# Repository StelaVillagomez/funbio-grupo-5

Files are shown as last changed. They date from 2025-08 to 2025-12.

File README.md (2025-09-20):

# Grupo5-Fun.Bio.
Bienvenidos al GitHub del grupo 5 :) Este repositorio contiene el proyecto realizado por el Grupo 5 de estudiantes del cuarto ciclo de Ingeniería Biomédica para el curso Fundamentos de Biodiseño.
Nuestro objetivo fue resolver un desafío real mediante el diseño y desarrollo de un dispositivo biomédico, aplicando conocimientos en electrónica, modelado 3D, investigación y prototipado.

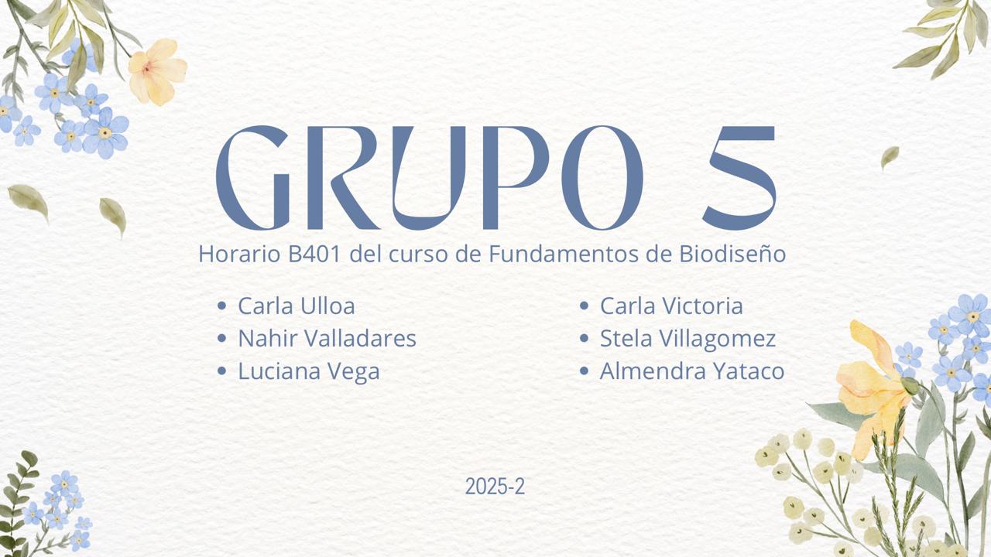
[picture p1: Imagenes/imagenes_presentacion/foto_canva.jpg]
imagen de canva

# Presentación:)

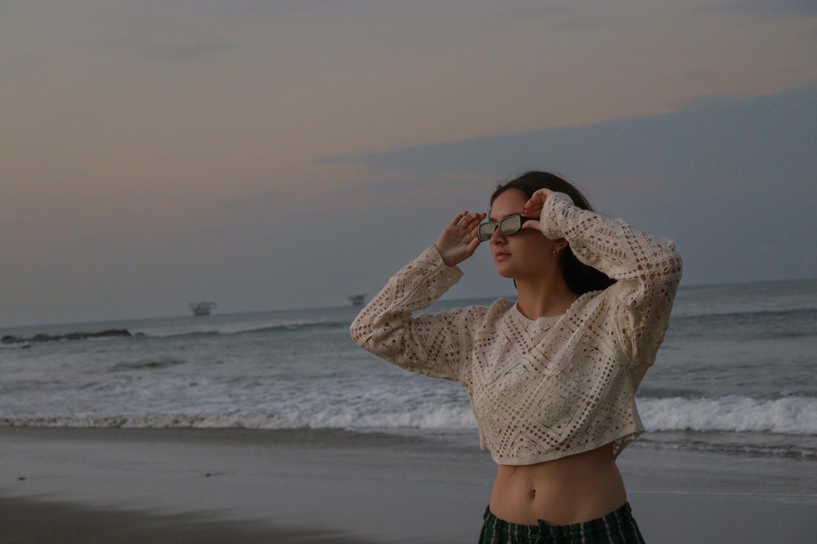
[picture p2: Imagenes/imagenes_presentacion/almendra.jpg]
imagen de WhatsApp

- **Almendra Yataco**
  - **Edad:** 18 años
  - **Sobre mí:** Me gusta compartir con mis amigos y probar cosas nuevas para salir de la rutina 
  - **Rol:** Programadora
  - **Responsabilidades:**
    - Implementar movimientos y funciones
    - Probar y corregir errores del sistema
    - Integrar modelos y elementos gráficos
      
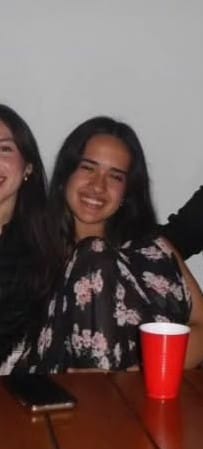
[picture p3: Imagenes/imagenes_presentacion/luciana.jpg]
imagen de WhatsApp

- **Luciana Vega**
  - **Edad:** 18 años
  - **Sobre mí:** Me encanta la tecnología aplicada a la salud. También disfruto salir con mis amigos y aprovechar cada momento al máximo.
  - **Rol:** Modeladora 3D
  - **Responsabilidades:**
    - Crear modelos tridimensionales
    - Aplicar texturas y materiales
    - Optimizar y adaptar los modelos para el proyecto
      
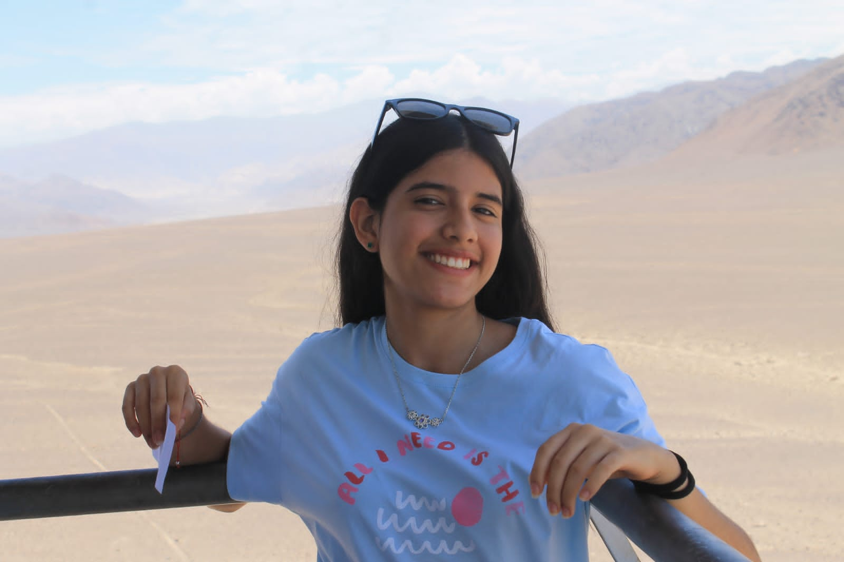
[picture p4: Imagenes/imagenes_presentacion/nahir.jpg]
imagen de WhatsApp

- **Nahir Valladares**
  - **Edad:** 18 años
  - **Sobre mí:** Me encanta la danza, aficionada por la ciencia y la tecnología, siempre dispuesta a aprender
  - **Rol:** Electrónica
  - **Responsabilidades:**
    - Apoyo en el desarrollo del sistema eléctrico
    - Elaboración del sistema y organización de componentes 
    - Verificación de electrónica y funcionamiento del proyecto
      
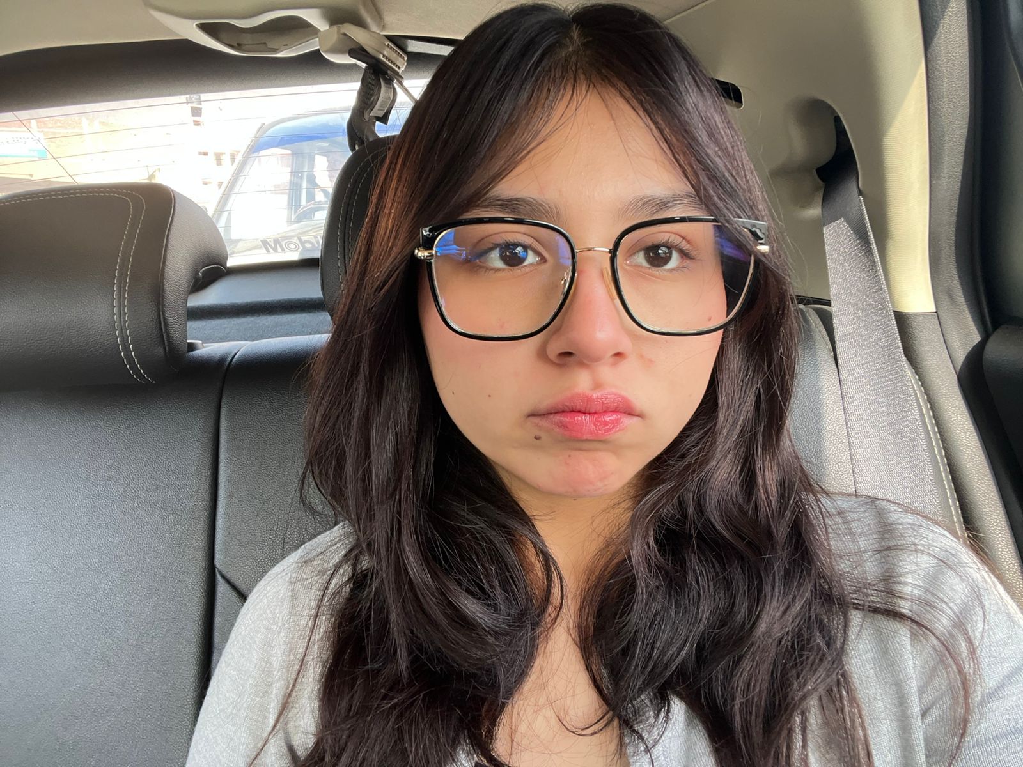
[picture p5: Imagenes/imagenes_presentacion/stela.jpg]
imagen de WhatsApp

- **Stela Villagomez**
  - **Edad:** 18 años
  - **Sobre mí:** Me gusta escuchar música, leer y ver series. Me apasiona resolver problemas, enfrentar nuevos retos y aprender cosas nuevas.
  - **Rol:** Coordinadora General
  - **Responsabilidades:**
    - Organización y coordinación del equipo
    - Planificación y supervisión de actividades
    - Asegurar el cumplimiento de los objetivos del grupo
      
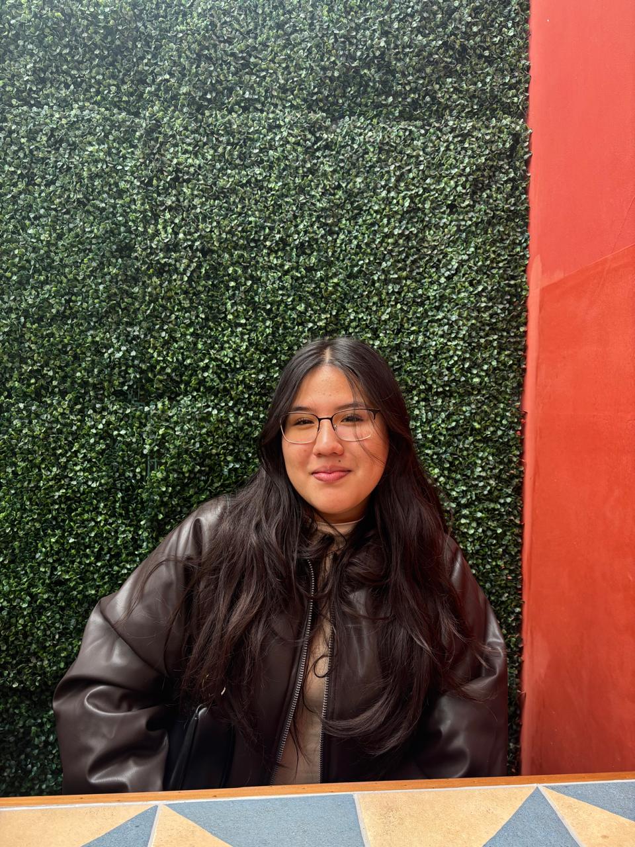
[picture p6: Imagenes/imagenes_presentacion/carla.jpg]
imagen de WhatsApp

- **Carla Victoria**
  - **Edad:** 18 años
  - **Sobre mí:** Ingeniera biomédica enfocada en crear soluciones que unan la ciencia y la tecnología al servicio de la salud.
  - **Rol:** Investigadora
  - **Responsabilidades:**
    - Buscar información relevante para el proyecto
    - Analizar y seleccionar datos útiles
    - Compartir hallazgos con el equipo
      
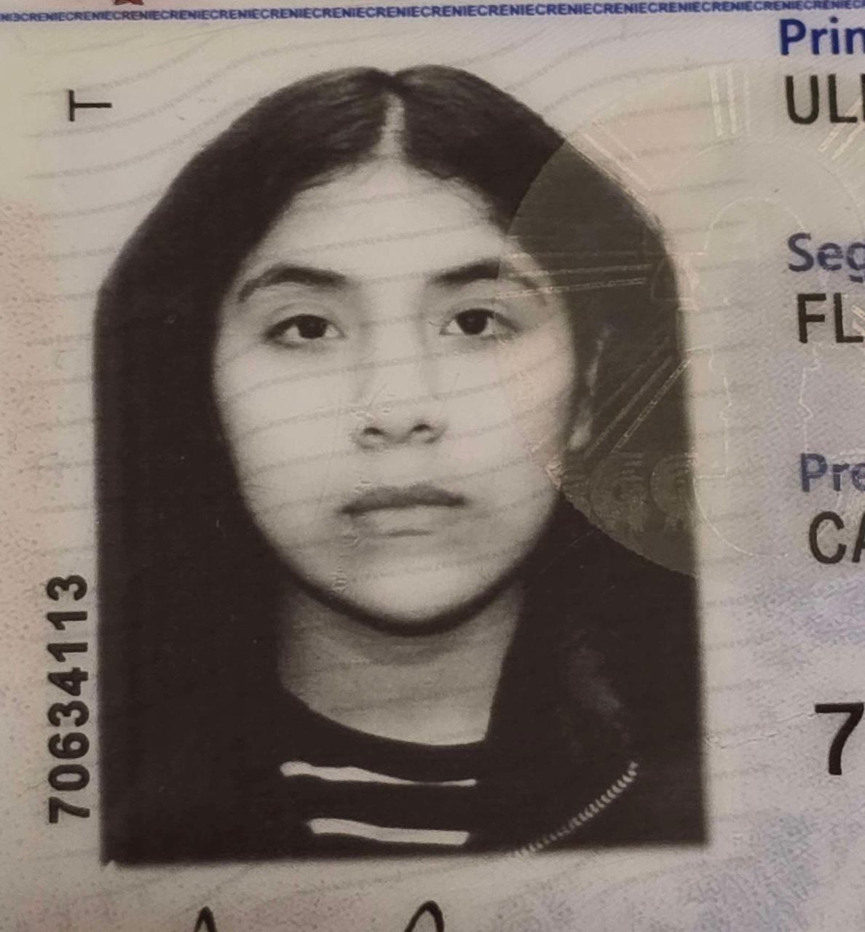
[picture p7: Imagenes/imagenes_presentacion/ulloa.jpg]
imagen de WhatsApp

- **Carla Ulloa**
  - **Edad:** 18 años
  - **Sobre mí:** Apasionada por las imágenes biomédicas y el desarrollo de nuevas tecnologías
  - **Rol:** Diseño 3D y Gestora del Repositorio
  - **Responsabilidades:**
    - Diseño y modelado 3D de estructuras y dispositivos biomédicos utilizando software especializado
    - Optimización y adaptación de modelos 3D para su aplicación en tecnologías biomédicas
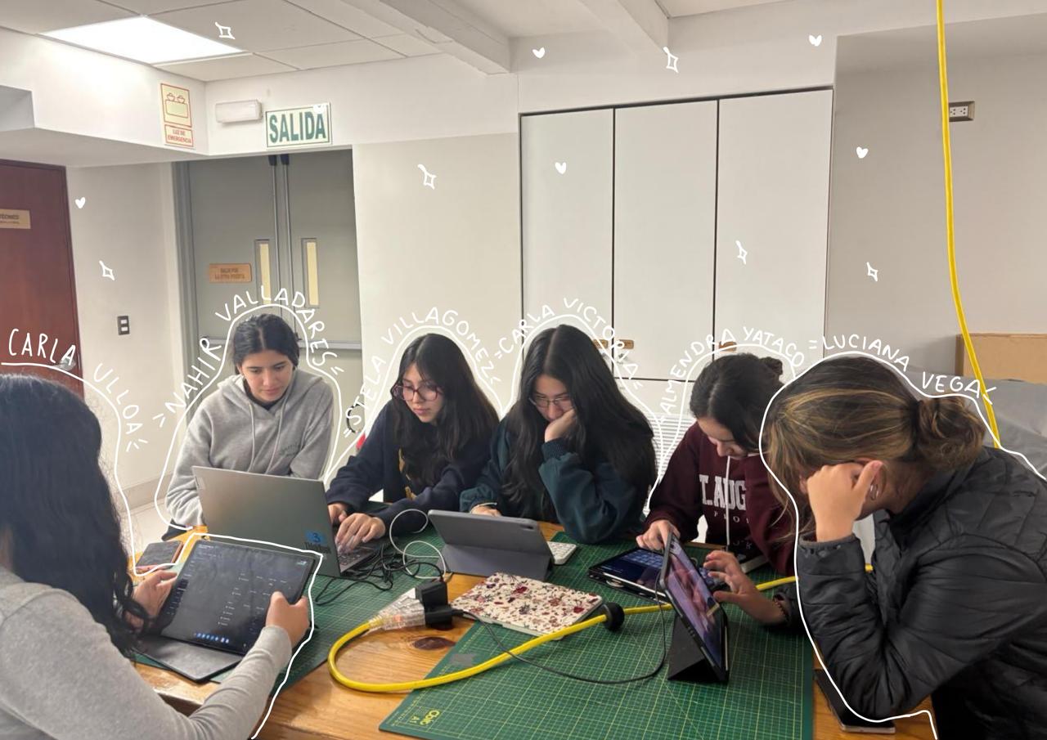
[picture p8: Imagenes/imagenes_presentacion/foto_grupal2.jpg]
imagen de WhatsApp


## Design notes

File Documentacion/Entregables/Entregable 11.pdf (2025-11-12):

# ENTREGABLE 11

### Integrantes: Carla Ulloa Florián Nahir Valladares Santur Luciana Vega Llanos Carla Victoria Quispe Stela Villagomez Altamirano Almendra Yataco Diaz

### Profesor: Juan Manuel Zuñiga

### Curso: Fundamentos de Biodiseño

2025

### 1. VERIFICACIÓN DEL DISEÑO SOFTWARE

Lista de funcionalidades

Función | Mecanismo
Recolección de fecha de la sesión de rehabilitación | Recepción de datos ingresados por el usuario sobre el día, mes y año de la sesión.
Recolección de datos de flexión de la mano (máximo anatómico) | Recepción de datos mediante sensor flex y el ESP32
Muestra del progreso sesión a sesión mediante una gráfica (Flexión vs tiempo) | Procesamiento de datos mediante aplicaciones de google (google sites, google sheets, etc)
Ordena la repetición del movimiento. | Al presionar un botón en la pantalla el usuario ordenará al exoesqueleto que repita la función de extender

Diseño de la interfaz:

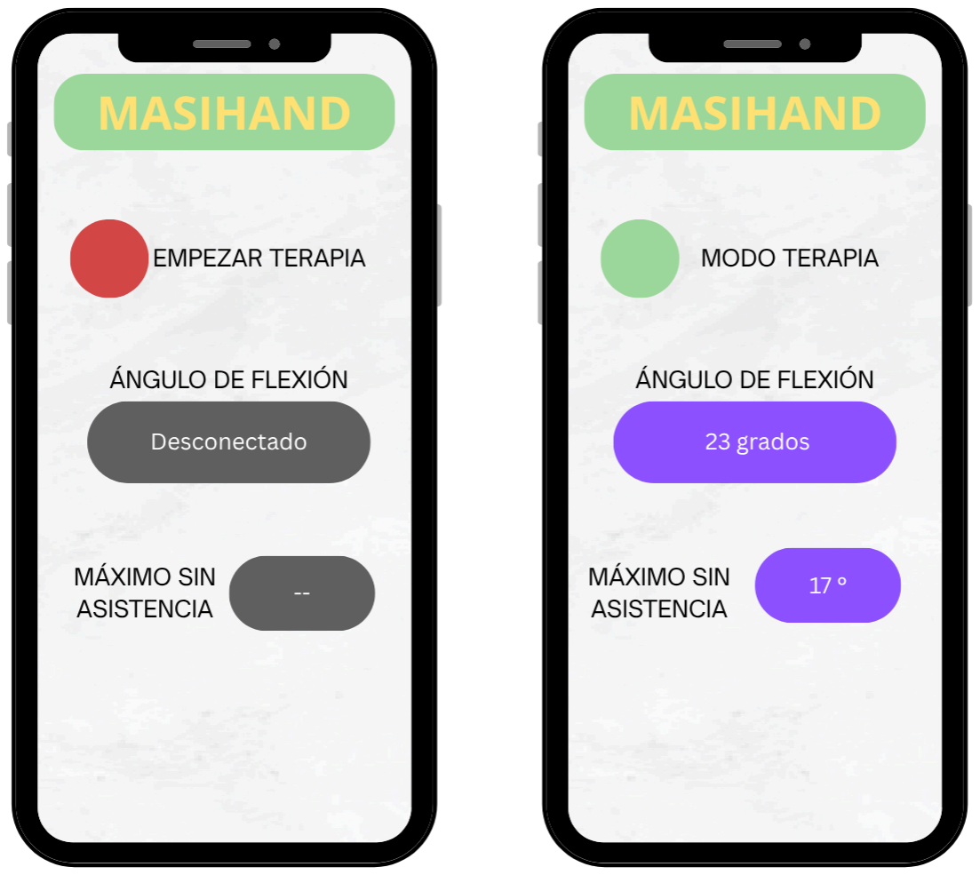
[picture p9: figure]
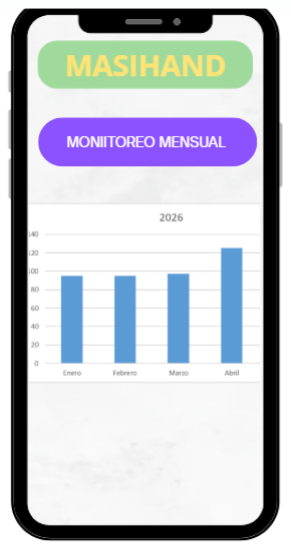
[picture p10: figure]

### 2. VERIFICACIÓN DEL DISEÑO HARDWARE

Preguntas de verificación

- ¿Cuánto peso debe tener el dispositivo?

El guante debe ser liviano para no causar fatiga. El conjunto total (guante, muñequera y caja externa) no debe superar los 700 gramos. Se verificará pesando cada parte y realizando una prueba de confort con el usuario. El diseño cumple si el peso total no excede los 700 g y no genera molestias tras una sesión de 30 minutos.

- ¿Cuánto tiempo debe durar la batería del dispositivo?

El guante, alimentado por baterías de 7 voltios, debe funcionar al menos durante tres sesiones de 30 minutos sin recarga, garantizando continuidad en la terapia. Se verificará mediante una prueba de descarga con el sistema activo, y se aceptará si mantiene su rendimiento por un mínimo de 90 minutos continuos.

- ¿Qué fuerza debe ejercer el guante para abrir los dedos del paciente?

El sistema debe generar entre 10 y 20 newtons por dedo para asistir la extensión y vencer la espasticidad moderada. La fuerza se medirá con un dinamómetro o sensor de carga. El dispositivo será aceptado si alcanza al menos 10 N por dedo con movimientos suaves y controlados.

- ¿Cómo debe funcionar el botón físico de control?

El guante posee un botón externo que inicia o detiene el movimiento. Debe ser accesible, resistente y responder con rapidez. Se probará su durabilidad con pruebas de pulsaciones y su tiempo de respuesta. Cumple el requisito si detiene el motor en menos de 0.5 segundos y mantiene un funcionamiento estable.

- ¿Qué precisión deben tener los sensores de flexión del guante?

Los sensores que miden el ángulo de movimiento deben tener una precisión de ±5° respecto a un goniómetro clínico. Se verificará comparando ambas lecturas, y el sistema será aceptado si el error no supera los ±5°.

- ¿Cómo se garantiza la seguridad del usuario durante la terapia?

El guante no debe generar calor excesivo ni movimientos bruscos. Su temperatura superficial debe mantenerse por debajo de 45 °C y los materiales deben ser cómodos y no irritantes. Se verificará mediante pruebas térmicas y de uso, y se aprobará si no causa molestias ni lesiones.

Requerimiento de Diseño | Resultado del Test
Se deben incorporar flexómetros que registren los ángulos máximos de flexión de los dedos. | Se integraron cinco flexómetros, uno por dedo, capaces de medir el ángulo de flexión y registrar el valor máximo alcanzado durante la terapia.
El sistema debe realizar el movimiento de | El movimiento de extensión se logra

extensión de los dedos mediante un mecanismo controlado. | mediante la tracción de hilos accionados por motores DC gearbox, que tiran de cada dedo de manera sincronizada para asistir la extensión.
Se debe seleccionar un sistema de ajuste que permita fijar el dispositivo en la mano del usuario durante su uso. | En este diseño se utilizó velcro para sujetar el exoesqueleto a cada dedo, permitiendo un ajuste firme, anatómico y fácil de colocar o retirar.
El sistema debe poder ser operado fácilmente por el terapeuta o el paciente. | El dispositivo fue diseñado con una interfaz clara y controles accesibles, lo que permite que tanto el terapeuta como el usuario pueda manipularlo sin dificultad durante la terapia.
El sistema debe visualizar el progreso del paciente a lo largo de las sesiones terapéuticas. | Se incorporó una función de visualización gráfica que muestra la evolución de la flexión de los dedos en función del tiempo mediante aplicaciones de google, permitiendo comparar los resultados sesión a sesión.

### 3. VERIFICACIÓN DEL DISEÑO

Tabla de verificación del prototipo
Funcionalidad | Cumplimiento
Sí | No
Realiza el movimiento de extensión de los dedos mediante tracción de hilos controlada por motores | X
Se calibra previamente el ángulo máximo alcanzable por cada dedo antes de iniciar la terapia | | X
Detecta el intento de extensión voluntaria del paciente y activa la asistencia automáticamente | | X
Limita la fuerza aplicada por los motores para evitar sobreextensión o daño en las articulaciones | X
Mide los ángulos de articulación en tiempo real durante la sesión | | X
El sistema se enciende y | X

apaga mediante un botón

El guante se adapta anatómicamente a la mano del paciente sin generar puntos de presión | X
El sistema puede ser operado fácilmente por el terapeuta o el paciente | X
Permite obtener, procesar, transmitir y almacenar los datos de cada sesión | | X

Tabla de requerimientos

Video del funcionamiento del circuito con el código implementado:

WhatsApp Video 2025-11-08 at 17.14.00.mp4 (https://drive.google.com/file/d/1Z69DmLE_9ussa5wDSN-QYyFBH8f0N9FN/view?usp=drive_link)

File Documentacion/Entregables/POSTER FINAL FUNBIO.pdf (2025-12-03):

Introducción

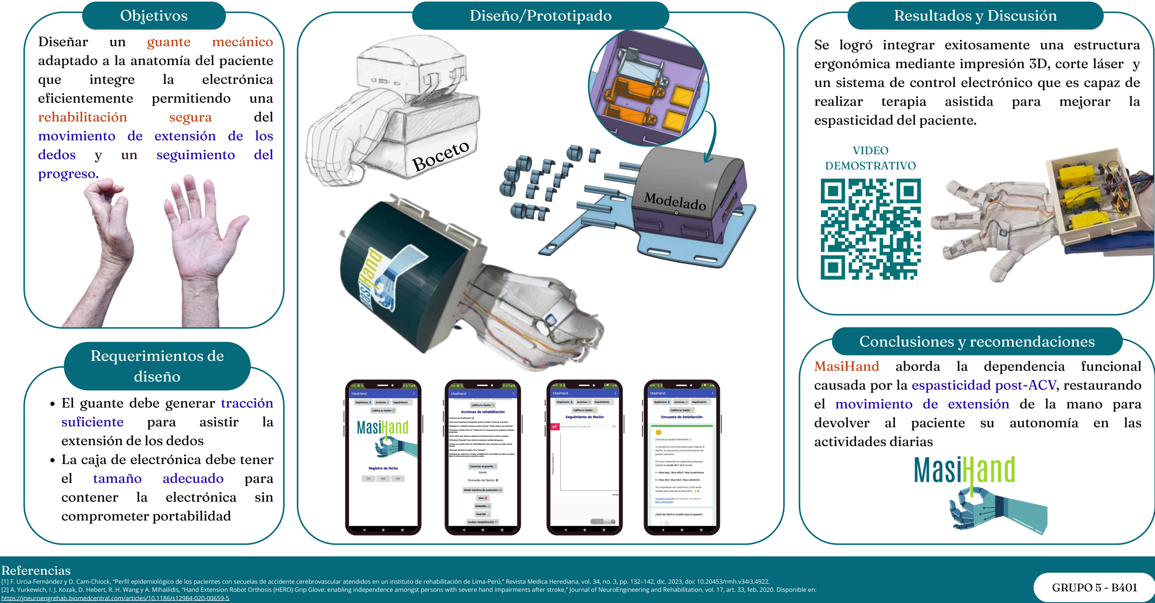
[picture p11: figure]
Objetivos; Modelado; Diseño/Prototipado; Resultados y Discusión; Conclusiones y recomendaciones; Requerimientos de diseño; El guante debe generar tracción; suficiente; para; asistir; extensión de los dedos La caja de electrónica debe tener; tamaño; adecuado; contener la electrónica sin comprometer portabilidad; Boceto; VIDEO DEMOSTRATIVO; MasiHand aborda la dependencia funcional; actividades diarias; GRUPO 5 - B401; Diseñar; guante; mecánico; adaptado a la anatomía del paciente; que; integre; electrónica; eficientemente permitiendo una; rehabilitación; segura; del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

causada por la espasticidad post-ACV, restaurando el movimiento de extensión de la mano para devolver al paciente su autonomía en las

Car

M

la Ulloa, Nahir

A

Valladares,

S

Luciana Ve

I

ga, C

H

arla Victori

A

a, Stela Villa

N

gomez y Alm

D

endra Yataco
Fundamentos de Biodiseño 2025-2, Ingeniería Biomedica, Facultad de Ciencias e Ingenieria

El ACV hemorrágico representa una causa mayor de discapacidad motora. Una de sus secuelas es la hemiplejía del cuerpo que afecta severamente la extremidad superior generando espasticidad y una flexión permanente de la mano, lo que compromete la independencia del paciente al realizar sus actividades de la vida diaria (AVD).

Se logró integrar exitosamente una estructura ergonómica mediante impresión 3D, corte láser y un sistema de control electrónico que es capaz de realizar terapia asistida para mejorar la

[1] F. Urcia-Fernández y D. Cam-Chiock, “Perfil epidemiológico de los pacientes con secuelas de accidente cerebrovascular atendidos en un instituto de rehabilitación de Lima-Perú,” Revista Medica Herediana, vol. 34, no. 3, pp. 132–142, dic. 2023, doi: 10.20453/rmh.v34i3.4922.
[2] A. Yurkewich, I. J. Kozak, D. Hebert, R. H. Wang y A. Mihailidis, “Hand Extension Robot Orthosis (HERO) Grip Glove: enabling independence amongst persons with severe hand impairments after stroke,” Journal of NeuroEngineering and Rehabilitation, vol. 17, art. 33, feb. 2020. Disponible en:
[3] E. Koltzi, D. Tzovaras, I. Kostavelis, P. Sideridis y K. Piliounis, “System and method for stroke rehabilitation using position feedback based exoskeleton control,” U.S. Patent 11,141,341 B2, 12-oct-2021.
[4] R. J. Adams, C. M. Westbrook y C. W. Olinger, “System, device and method for tracking the human hand,” U.S. Patent 11,696,704 B1, 11-jul-2023.

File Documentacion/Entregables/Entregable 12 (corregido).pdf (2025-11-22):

# ENTREGABLE 12

Integrantes:
Carla Ulloa Florián
Nahir Valladares Santur
Luciana Vega Llanos
Carla Victoria Quispe
Stela Villagomez Altamirano Almendra Yataco Diaz

Profesor:
Juan Manuel Zuñiga

Curso:
Fundamentos de Biodiseño

2025

PLAN DE USABILIDAD BASADO EN EVIDENCIAS Sección del
plan
¿Qué es? | ¿Qué hacer? | ¿Qué evidencia deben
incluir?

Contexto de
uso

El guante mecánico con
exoesqueleto
(“MasiHand”) | fue
desarrollado | con el
propósito de asistir en el
tratamiento | de | una
mano | en | tensión
permanente | en | una
paciente de 55 años. El
dispositivo | será
utilizado dentro de un
centro de rehabilitación,
bajo la supervisión del
doctor | o | terapeuta
responsable del caso,
quien se encargará de
garantizar | su | uso
adecuado | y | de
monitorear la evolución
del paciente en cada
sesión.
Para iniciar la sesión, el personal especializado
ayuda a colocar el
guante favoreciendo la
flexión de la muñeca, lo
cual genera la apertura
de los dedos y permite
posicionar el dispositivo
correctamente sobre la
mano. | Una | vez
colocado, se ajustan los
velcros individuales de
cada | dedo | para
asegurarlo al guante.
Posteriormente, se
posiciona la férula y se
fija mediante el velcro
correspondiente, junto

El público objetivo de
MasiHand son pacientes
que presentan una mano
en flexión en distintos
grados de severidad y
que buscan recuperar el
movimiento | de
extensión de su mano
afectada para retomar
actividades diarias y
favorecer | su
independencia
funcional. Debido a
estas necesidades, el
dispositivo | será
utilizado en un centro
de rehabilitación bajo la
supervisión del doctor o
terapeuta encargado del
caso.
En este entorno, el
profesional de salud
asistirá al paciente en la colocación correcta del
guante en cada sesión.
Durante | la | sesión
introductoria, | el
terapeuta explicará el
funcionamiento general
del | dispositivo | y
realizará la calibración
de los ángulos máximos
de las articulaciones de
los dedos del paciente,
con el fin de establecer
un | rango | de
movimiento seguro y
evitar | dolor | y/o
hiperflexión

Se adjunta el modelado
final

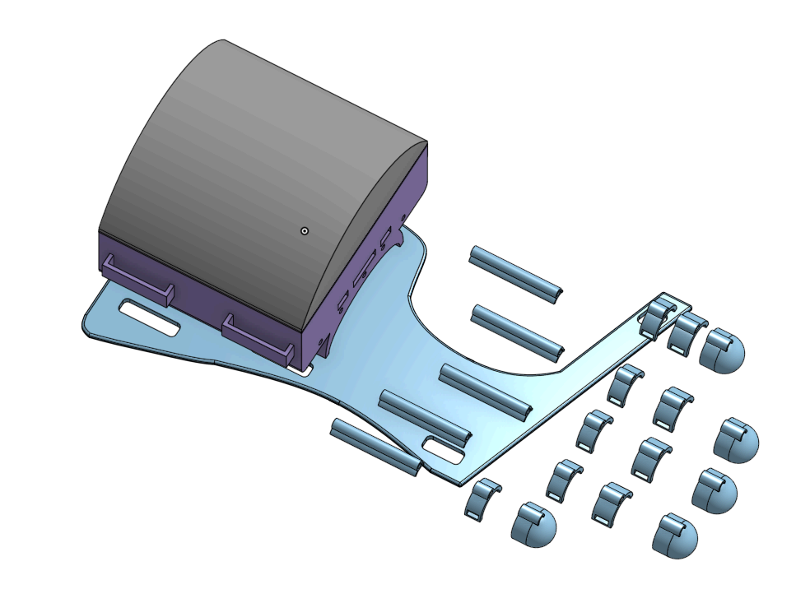
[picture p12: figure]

En la siguiente foto se
muestran los soportes
para los componentes
dentro de la caja de la
muñequera. | Las | 2
cajitas | cuadradas
corresponden | a | los
soportes para drivers.
Mientras que las otras 3
piezas son soportes para
los motores gearbox
yellow

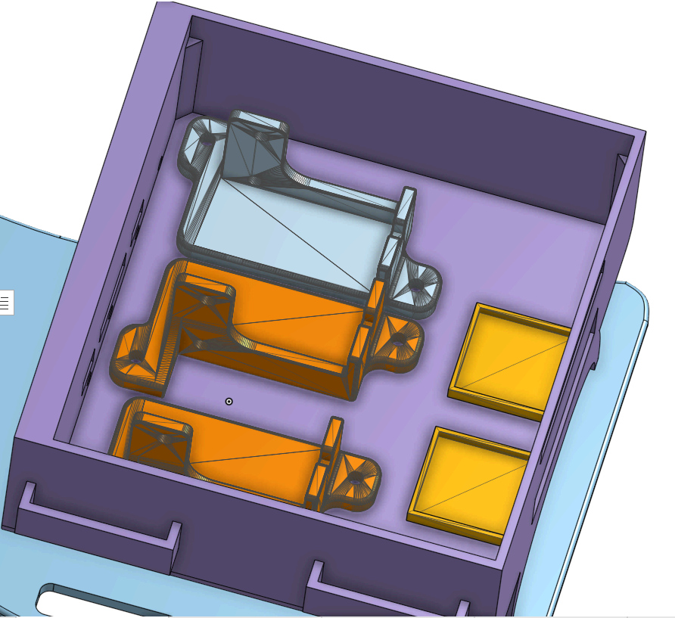
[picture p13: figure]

al | soporte | de | la
muñequera.
Con | todos | | los
componentes ajustados,
la | paciente | queda
preparada | para
comenzar su sesión de
rehabilitación. En la
sesión introductoria, los
ángulos máximos de
flexión son establecidos
y guardados. Como
primer paso, el paciente
intentará | abrir | lo
máximo que pueda con
su propia fuerza, luego
el dispositivo registra
este dato y lo guarda en
una | gráfica | | para
observar su progreso.
Luego, el dispositivo
activa su asistencia
activa para culminar el
movimiento de flexión.

Una vez definida esta
calibración inicial, el
proceso | de
rehabilitación incluirá
cuatro sesiones activas
de flexión de entre 2 y 3
minutos | cada | una,
intercaladas | con
descansos de 2 minutos,
según el criterio del
profesional a cargo.
Este | conjunto | de
sesiones se realizará
tres veces por semana,
en | días | alternados,
siguiendo un esquema
de | uso | regular | y
progresivo que busca
favorecer | la
recuperación | del
movimiento funcional.

Finalmente se adjunta
una foto del prototipo
para la extensión de un
dedo

Perfil del
usuario
El | usuario | posee
habilidades cognitivas
tales | | como
conocimiento | en
costura, un estado de
conciencia lúcido,en el
caso | de | sus
características | físicas
posee | hemiplejia
derecha espástica post
ACV hemorrágico , no
obstante muestra alta
motivación | por
recuperar autonomía en
actividades.
El | pronóstico
neurológico establece
un | déficit | motor
residual permanente y
El | usuario | | posee
limitaciones debido a su
leve | disartria,
ocasionándole | una
espasticidad moderada
con una pobre apertura
voluntaria en la mano
derecha ,pues esta mano
se encuentra en un
estado | de | flexión
permanente, adicional
presenta una limitación
cognitiva | tal | como
déficit motor residual
permanente.
En | cuanto | a | la
movilidad, la paciente
realiza la marcha de

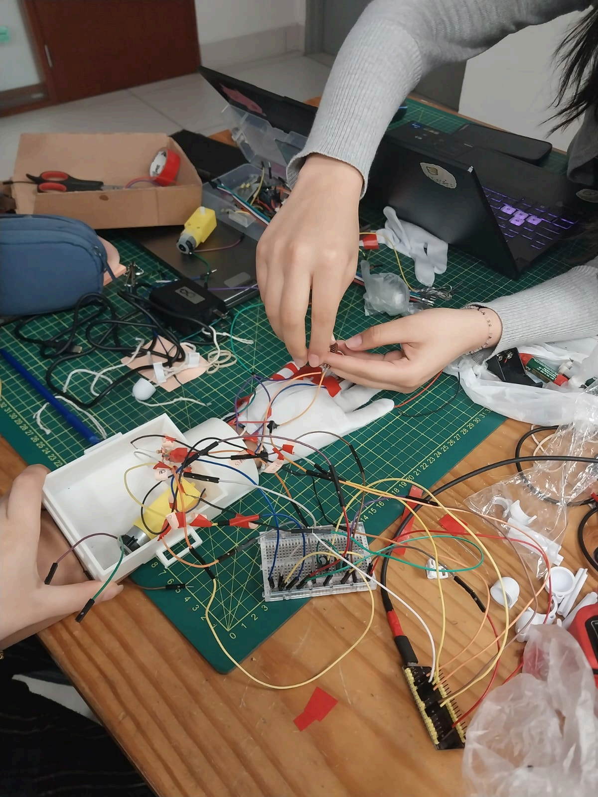
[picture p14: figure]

Evidencia basada en el
caso clínico presentado
a nosotros.

Ficha resumen del caso
clínico:
Paciente: Mujer, 55
años
Diagnóstico:
Hemiplejía | | derecha
espástica | | post-ACV
hemorrágico
Antecedentes:
Hipertensión arterial
mal controlada
Estado | | actual:
Espasticidad moderada
(Ashworth 2–3), mano
derecha | en | flexión

se | espera | una
recuperación funcional
parcial con limitación
persistente en la mano
derecha.

manera insegura con la
ayuda de un bastón de
cuatro | apoyos. | Su
funcionalidad inicial es
de dependencia parcial
en Actividades de la
Vida Diaria (AVD),
aunque | logra
alimentarse
independientemente con
su mano izquierda.

permanente, leve
disartria, marcha con
bastón.
Dolor: | Tirantez | y
rigidez al extender la
mano.
Situación social: Vive
con esposo e hija; ex
costurera, ahora realiza
tareas ligeras.
Tratamientos previos:
Fisioterapia, | férula
nocturna, | baclofeno,
toxina botulínica.
Meta: Recuperar
autonomía en AVD y
funcionalidad de la
mano.

Análisis de
tareas
Corresponde | a
identificar todas las
tareas necesarias para
usar el prototipo de
rehabilitación de forma
correcta | y | segura.
Incluye las acciones
previas, | durante | y
después de la sesión, así
como las tareas que
implican riesgo si se
realizan
incorrectamente (por
ejemplo, sobreextender
una | articulación,
colocar mal la férula,
etc.).
1. Verificar que el
paciente haya
sido instruido por
el terapeuta sobre
el | uso | del
dispositivo.
2. Realizar | 4
sesiones, | cada
una separada por
descansos de 2
minutos.
3. Favorecer la
extensión de la
muñeca | para
facilitar | la
extensión de los
dedos | | con
espasticidad.
4. Colocar el guante
en la mano del
paciente.
5. Ajustar
correctamente los
velcros del

El prototipo permite
mover los dedos de
manera | asistida | y
controlada por límites
anatómicos, | medidos
mediante | sensores
flexibles (flex sensors)
integrados en el guante.
Estos sensores registran
el | ángulo | de | las
articulaciones en tiempo
real, con los flex se
pueden | calibrar los
ángulos | máximos
alcanzables. | Esto
implica, que la fuerza
aplicada | por | los
motores evita una sobre
tensión o daño en el
paciente. Los motores
DC | ejecutan | el
movimiento únicamente
dentro del rango que el
usuario | definió

guante.
6. Ajustar la caja de
componentes y
asegurarla en la
férula.
7. Encender el
sistema
presionando | el
botón | | de
encendido.
8. En la app (MIT
App Inventor),
presionar “Medir
máximo de
extensión”.
9. Los | | motores
giran en sentido
horario hasta
que el usuario
presione el
pulsador “1” (los
motores se
detienen).
10.Los | | motores
giran en sentido
anti-horario para
desenrollar la
mano hasta que
el | | usuario
presione “Alto”
en la app.
11.El usuario puede
presionar
“Extender” | y
“Alto” | | cuantas
veces | | desee
según la duración
de la sesión (2 a
3 minutos).
12.En | la | app,
presionar
“Acabar
rehabilitación”.
13.Apagar | el

mediante los botones
“1”, | “Alto”, | y
posteriormente
“Extender”. Esto lo
convierte en un sistema
seguro | incluso | en
pacientes | | con
espasticidad. El guante
de tela, se adapta
anatómicamente a la
mano del paciente sin
generar | puntos | de
presión.

La tarea de medir el
máximo de extensión es
considerada crítica
porque durante este
proceso los motores A,
B y C giran en sentido
horario para extender
los dedos hasta que el
usuario | presiona | el
botón | físico | “1”,
momento en el cual los
motores se detienen. Si
esta acción no se
ejecuta adecuadamente,
existe el riesgo de
generar | | una
sobreextensión
articular, lo cual podría
causar dolor en los
dedos.

equipo.
14.Retirar el guante
y luego la férula.

Criterios de
éxito

Define las métricas que
permiten evaluar la
efectividad y usabilidad
del dispositivo.

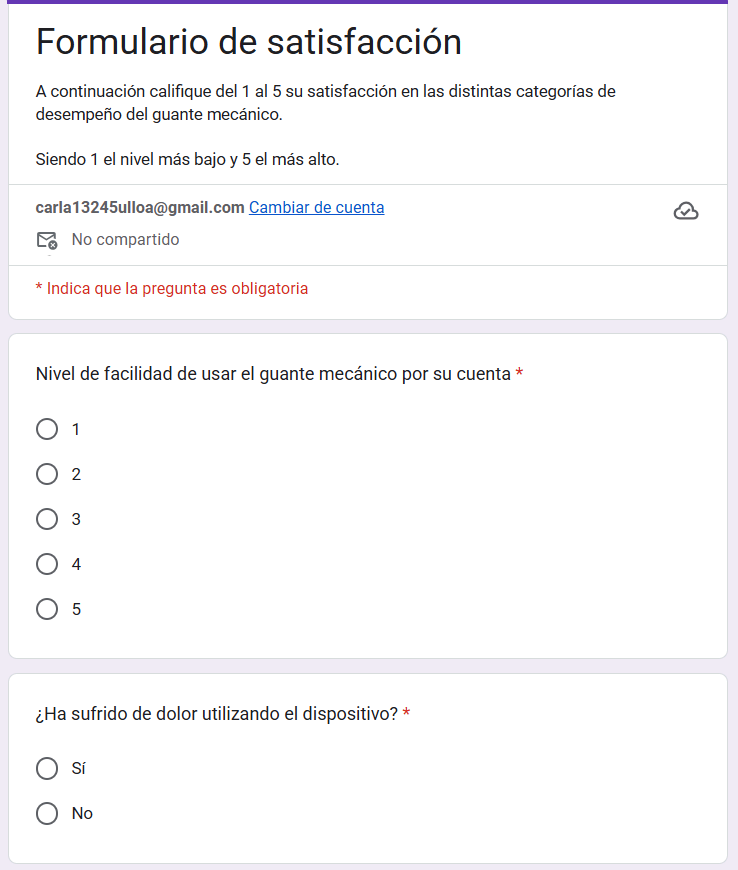
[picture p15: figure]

Se toman en cuenta las
opiniones del paciente y
se utiliza el feedback
para mejorar a futuro

Métricas cualitativas:
Son | medidas
descriptivas y subjetivas
que se utilizan para
comprender el "por
qué" detrás de los
números. Se centran en
la | experiencia, | la
percepción y la opinión.

Métricas cuantitativas:
Son valores numéricos
y estadísticos que se
utilizan para medir y
evaluar el rendimiento
de manera precisa y
objetiva.
- Satisfacción: El
paciente se siente
cómodo,
motivado y
seguro al usar el
guante.
- Seguridad: | no
presenta | dolor,
lesiones | ni
movimientos
bruscos durante
el uso.
- Integridad
Física: Ausencia
de | marcas,
rozaduras | o
lesiones cutáneas
relacionadas con
el uso del guante.
- Adherencia: la
paciente
mantiene el uso
regular | del
dispositivo | en
casa.
- Disposición del
paciente | a
recomendar | el
dispositivo | a
otros
usuarios/paciente
s
- Motivación:
Incremento en la
disposición
reportada | para
realizar | los
ejercicios.

Para las métricas
cuantitativas se utiliza
un
google forms y una
escala numérica.
Para | | métricas
cualitativas se tomará
en | cuenta | las
sugerencias del paciente
y preguntas abiertas.

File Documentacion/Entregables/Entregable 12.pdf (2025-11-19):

# ENTREGABLE 11

Integrantes:
Carla Ulloa Florián
Nahir Valladares Santur
Luciana Vega Llanos
Carla Victoria Quispe
Stela Villagomez Altamirano Almendra Yataco Diaz

Profesor:
Juan Manuel Zuñiga

Curso:
Fundamentos de Biodiseño

2025

PLAN DE USABILIDAD BASADO EN EVIDENCIAS Sección del
plan
¿Qué es? | ¿Qué hacer? | ¿Qué evidencia deben
incluir?

Contexto de
uso

Describe el entorno
físico, social y técnico
donde el usuario emplea
el | guante | de
rehabilitación
MasiHand
El | usuario | es | un
paciente con hemiplejía
post-ACV hemorrágico
con mano en flexión.
dispositivo | es | una
persona que ha sufrido
de ACV y
El | dispositivo | está
creado | para | ser
utilizado,
principalmente, en el
hogar del paciente. Para
ello, requiere de una
mesa/superficie plana,
segura y estable. El
paciente | será
previamente instruido
por su terapeuta sobre el
uso del dispositivo en
una | sesión
introductoria. Donde le
explicará | el
funcionamiento | del
sistema, | el | cual,
consiste, en que el
paciente | vía | una
aplicación móvil que
descargará en su celular
podrá inicializar su
movimiento | de
extensión | para | una
sesión de rehabilitación
de 30 minutos.
A | continuación | se
adjunta | foto | del
prototipo elaborado. Por
el momento, cuenta con
un | dedo | en
funcionamiento | para
poder | realizar | los
ajustes necesarios com:
1. Ajustar los
huecos por donde
pasan los cable
de los sensores
flex
2. Cambiar las
dimensiones de
la | caja | de
componentes
3. Añadir tela para
mantener los
sensores flex en
su lugar

Perfil del
usuario

Caracteriza al usuario
final del sistema, sus
limitaciones,
capacidades | y
motivaciones

Mujer de 55 años con
hemiplejía | derecha
espástica | (Ashworth
2–3), leve disartria, y
uso dominante de la


Evidencia basada en el
caso clínico presentado
a nosotros.

Ficha resumen del caso

mano izquierda. Vive
con su esposo e hija,
muestra alta motivación
por | recuperar
autonomía | | en
actividades | como
vestirse, | cocinar | y
escribir, | aunque
presenta frustración al
no poder usar su mano
derecha.

clínico:
Paciente: Mujer, 55
años
Diagnóstico:
Hemiplejía | derecha
espástica | post-ACV
hemorrágico
Antecedentes:
Hipertensión arterial
mal controlada
Estado | actual:
Espasticidad moderada
(Ashworth 2–3), mano
derecha | en | flexión
permanente, | leve
disartria, marcha con
bastón.
Dolor: | Tirantez | y
rigidez al extender la
mano.
Situación social: Vive
con esposo e hija; ex
costurera, ahora realiza
tareas ligeras.
Tratamientos previos:
Fisioterapia, | férula
nocturna, | baclofeno,
toxina botulínica.
Meta: Recuperar
autonomía en AVD y
funcionalidad de la
mano.

Análisis de
tareas

Identifica las acciones
que el usuario realiza o
debe aprender para
interactuar
correctamente con el
sistema
1. El paciente fue
previamente
instruido por su
terapeuta
2. Colocación del
guante
3. Colocar férula
para la extensión
de su muñeca
4. Presionar | el
Con | el | prototipo
planteado | se puede
realizar la extensión de
un dedo y con los flex
se puede calibrar los
ángulos | máximos
alcanzables. | Esto
implica, que la fuerza
aplicada | por | los
motores evita una sobre

botón | de
encendido
5. Registrar
movimiento
máximo del
paciente por si
mismo
6. Inicializar el
movimiento
predeterminado
durante 30
minutos
7. El | tiempo
terminado,
apagar el equipo
8. Retirar el guante
y luego la férula

tensión o daño en el
paciente. Asimismo,
con los flex se mide los
ángulos | de | las
articulaciones en tiempo
real. El paciente puede
apagar y encender el
circuito mediante un
botón. El guante de tela,
se | adapta
anatómicamente a la
mano del paciente sin
generar | puntos | de
presión.

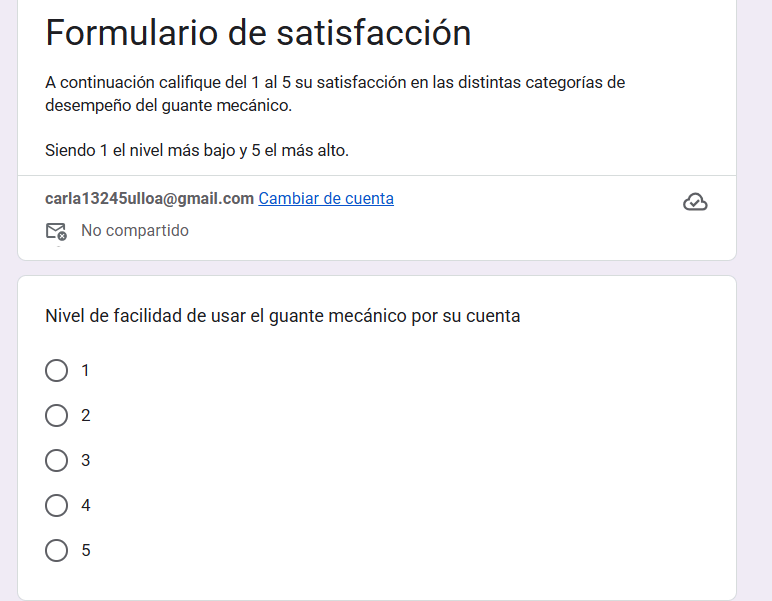
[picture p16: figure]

Criterios de
éxito

Define las métricas que
permiten evaluar la
efectividad y usabilidad
del dispositivo
- Satisfacción: El
paciente se siente
cómodo,
motivado y
seguro al usar el
guante.
- Seguridad: | no
presenta | dolor,
lesiones | ni
movimientos
bruscos durante
el uso.
- Adherencia: la
paciente
mantiene el uso
regular | del
dispositivo | en
casa.

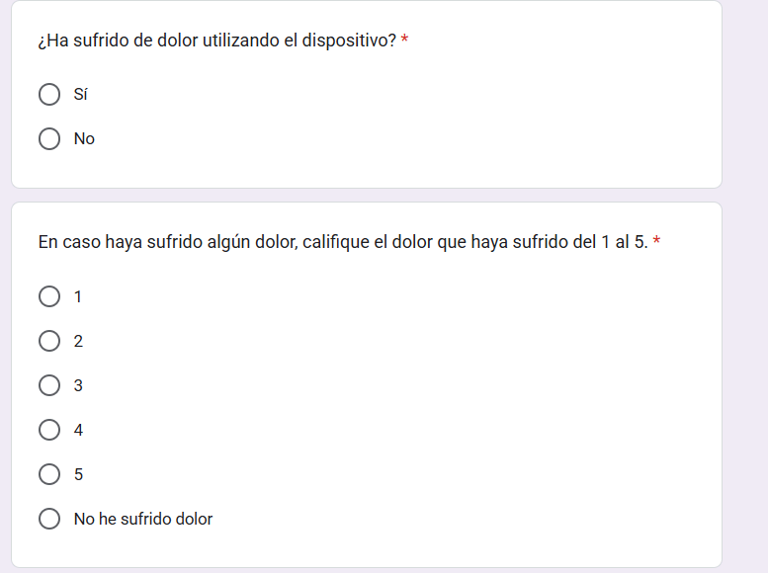
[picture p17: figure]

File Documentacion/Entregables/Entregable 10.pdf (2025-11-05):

# ENTREGABLE 10

Integrantes:
Carla Ulloa Florián
Nahir Valladares Santur
Luciana Vega Llanos
Carla Victoria Quispe
Stela Villagomez Altamirano Almendra Yataco Diaz

Profesor:
Juan Manuel Zuñiga

Curso:
Fundamentos de Biodiseño

2025

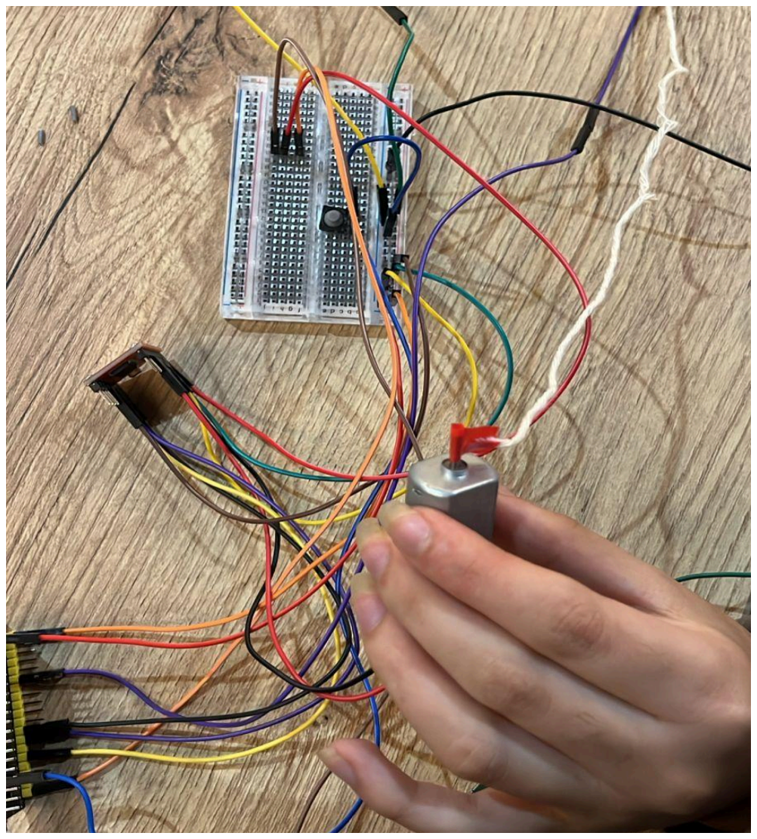
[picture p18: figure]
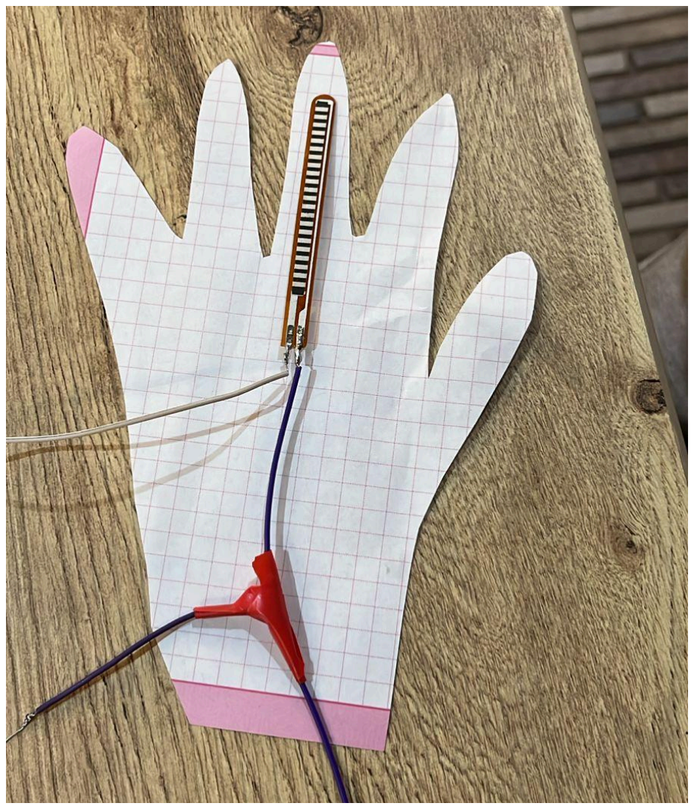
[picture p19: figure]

PROTOTIPADO ELECTRÓNICO FUNCIONAL Imágenes del prototipo del circuito:

Link a un drive con los videos del circuito funcionando: CIRCUITO FUNCIONAL (VIDEO) (https://drive.google.com/drive/folders/1bDZlOI_BwbkhJdF6kLeNzqcfPtznsMCS?usp=sharing)

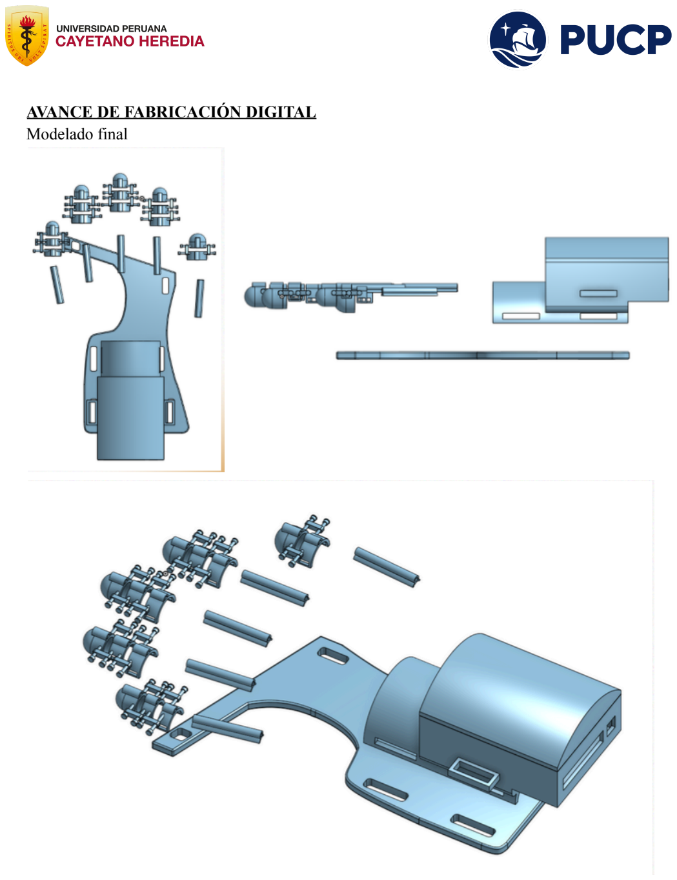
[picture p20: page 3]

AVANCE DE FABRICACIÓN DIGITAL Modelado final

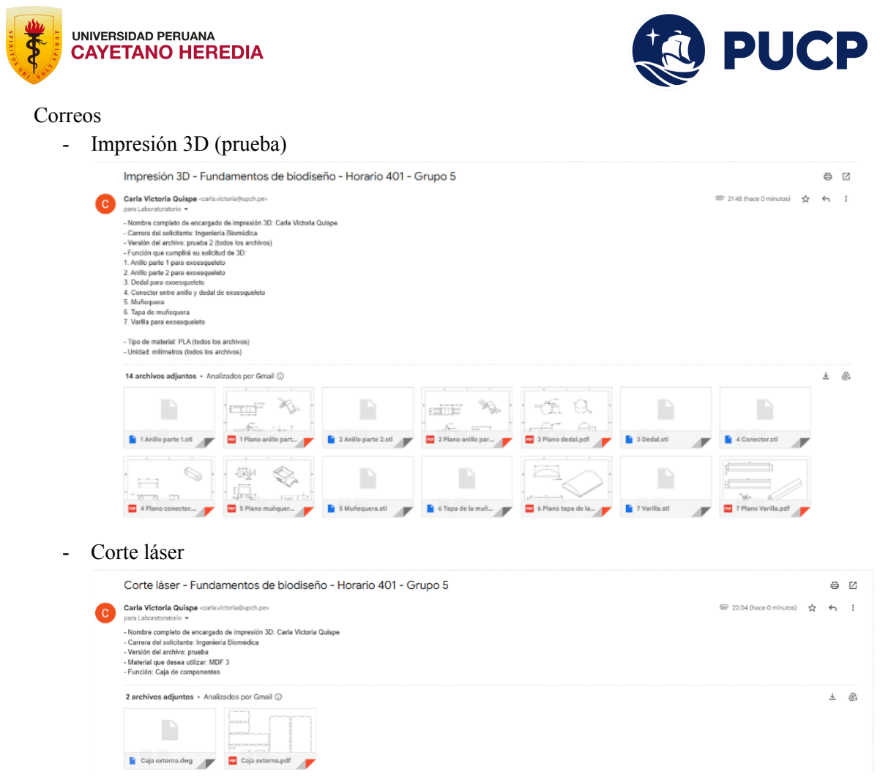
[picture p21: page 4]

Correos
- Impresión 3D (prueba)
- Corte láser

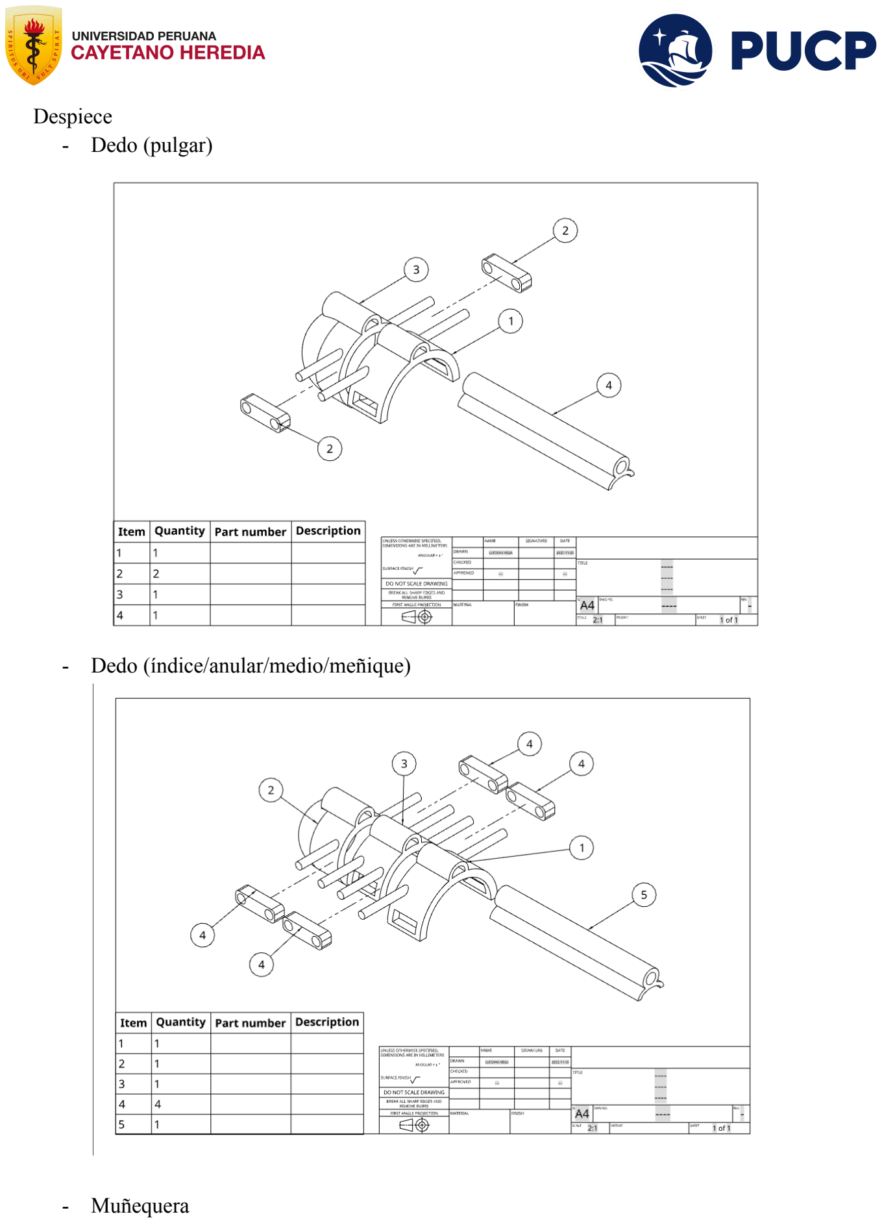
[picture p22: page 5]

Despiece
- Dedo (pulgar)
- Dedo (índice/anular/medio/meñique)
- Muñequera

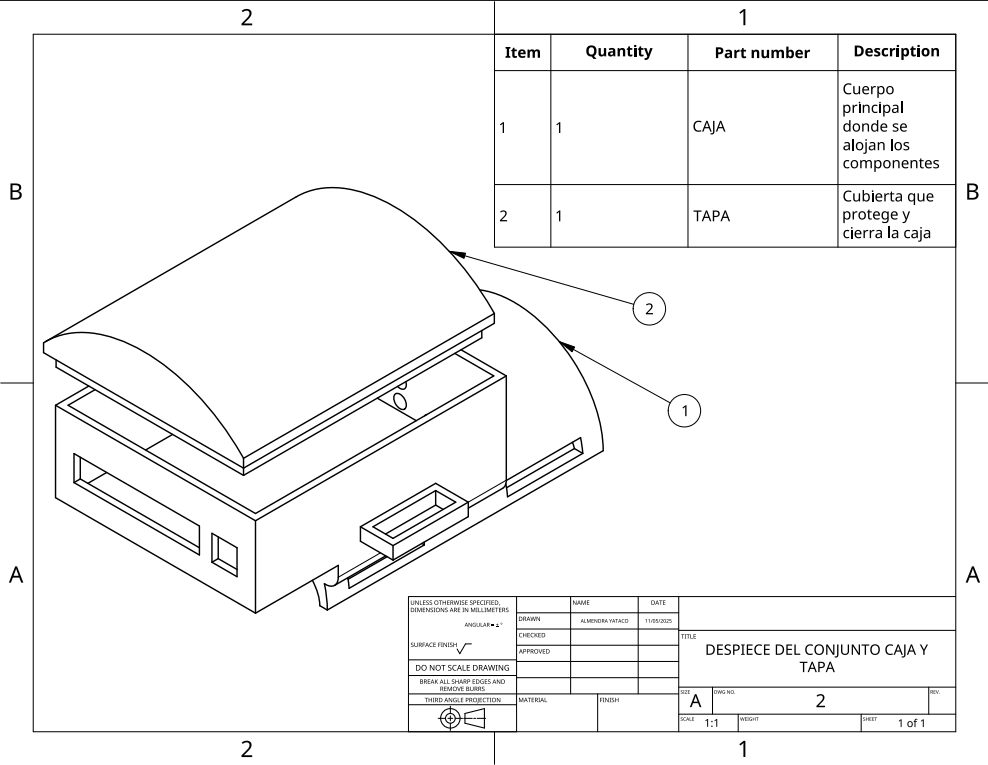
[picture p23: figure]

Animación
ANIMACIÓN FINAL (VIDEO) (https://drive.google.com/drive/folders/14FYSgebfoRpwsloNqLz4rAWp2asAcTHl?usp=sharing)

PLAN DE USABILIDAD BASADO EN EVIDENCIAS Sección del
plan
¿Qué es? | ¿Qué hacer? | ¿Qué evidencia deben
incluir?

Contexto de
uso

Describe el entorno
físico, social y técnico
donde el usuario emplea
el | guante | de
rehabilitación
MasiHand
El | usuario | es | un
paciente con hemiplejía
post-ACV hemorrágico
con mano en flexión.
dispositivo | es | una
persona que ha sufrido
de ACV y
El | dispositivo | está
creado | para | ser
utilizado,
principalmente, en el
hogar del paciente. Para
ello, requiere de una
mesa/superficie plana,
segura y estable. El
paciente | será
previamente instruido
por su terapeuta sobre el
uso del dispositivo en
una | sesión
introductoria. Donde le
explicará | el
funcionamiento | del
sistema, | el | cual,
consiste, en que el
paciente | vía | una
aplicación móvil que
descargará en su celular
podrá inicializar su
movimiento | de
extensión | para | una
sesión de rehabilitación
de 30 minutos.
A | continuación | se
adjunta foto de la
colocación | del
dispositivo | en | un
modelado 3D

Perfil del
usuario

Caracteriza al usuario
final del sistema, sus
limitaciones,
capacidades | y
motivaciones

Mujer de 55 años con
hemiplejía | derecha
espástica | (Ashworth
2–3), leve disartria, y
uso dominante de la
mano izquierda. Vive

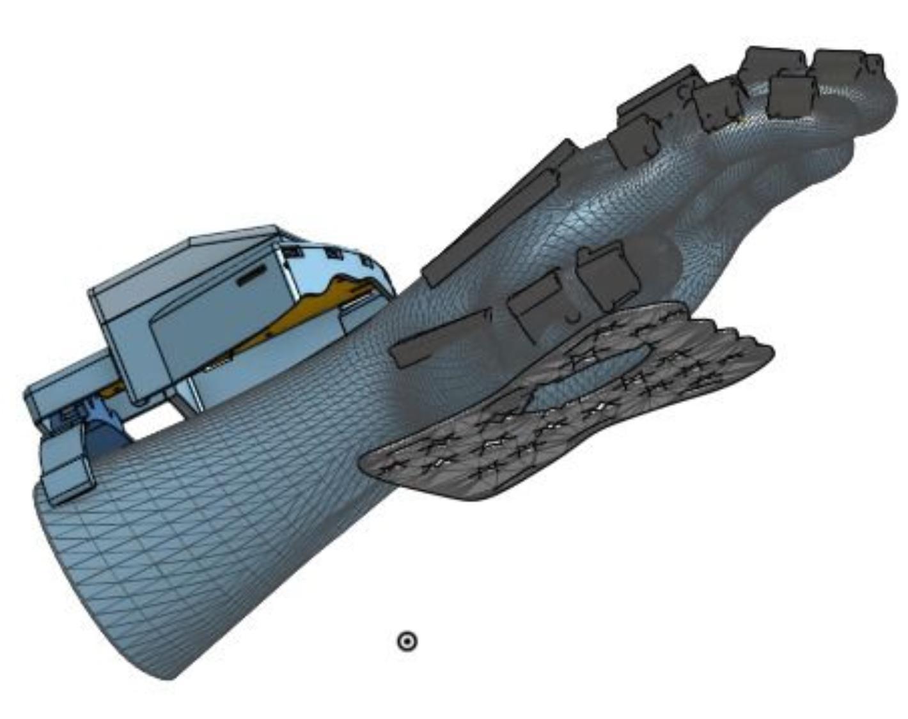
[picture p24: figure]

Evidencia basada en el
caso clínico presentado
a nosotros.

Ficha resumen del caso
clínico:

con su esposo e hija,
muestra alta motivación
por | recuperar
autonomía | | en
actividades | como
vestirse, | cocinar | y
escribir, | aunque
presenta frustración al
no poder usar su mano
derecha.

Paciente: Mujer, 55
años
Diagnóstico:
Hemiplejía | derecha
espástica | post-ACV
hemorrágico
Antecedentes:
Hipertensión arterial
mal controlada
Estado | actual:
Espasticidad moderada
(Ashworth 2–3), mano
derecha | en | flexión
permanente, | leve
disartria, marcha con
bastón.
Dolor: | Tirantez | y
rigidez al extender la
mano.
Situación social: Vive
con esposo e hija; ex
costurera, ahora realiza
tareas ligeras.
Tratamientos previos:
Fisioterapia, | férula
nocturna, | baclofeno,
toxina botulínica.
Meta: Recuperar
autonomía en AVD y
funcionalidad de la
mano.

Análisis de
tareas

Identifica las acciones
que el usuario realiza o
debe aprender para
interactuar
correctamente con el
sistema
1. El paciente fue
previamente
instruido por su
terapeuta
2. Colocar férula
para la extensión
de su muñeca
3. Colocación del
guante
4. Presionar | el
botón | de

El paciente conforme
vaya | | realizando
progresivamente | el
tratamiento debe poseer
la capacidad de realizar
una extensión , la
evidencia se basa en el
uso | del | dispositivo
como tal.

encendido
5. Registrar
movimiento
máximo del
paciente por si
mismo
6. Inicializar el
movimiento
predeterminado
durante 30
minutos
7. El | tiempo
terminado,
apagar el equipo
8. Retirar el guante
y luego la férula

Criterios de
éxito

Define las métricas que
permiten evaluar la
efectividad y usabilidad
del dispositivo
- Satisfacción: El
paciente se siente
cómodo,
motivado y
seguro al usar el
guante.
- Seguridad: | no
presenta | dolor,
lesiones | ni
movimientos
bruscos durante
el uso.
- Adherencia: la
paciente
mantiene el uso
regular | del
dispositivo | en
casa.
El | paciente | dará
feedback de su uso del
guante mecánico. Se
calificará en una escala
del 1 al 10 cada sección
y se tendrán en cuenta
comentarios para
mejorar a futuro.

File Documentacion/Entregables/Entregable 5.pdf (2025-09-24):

# ENTREGABLE 5

### Integrantes: Carla Ulloa Florián Nahir Valladares Santur Luciana Vega Llanos Carla Victoria Quispe Stela Villagomez Altamirano Almendra Yataco Diaz

### Profesor: Juan Manuel Zuñiga

### Curso: Fundamentos de Biodiseño

2025

IDENTIFICACIÓN DE LA NECESIDAD

La paciente es una mujer de 55 años con antecedentes de hipertensión arterial mal controlada y un accidente cerebrovascular (ACV) hemorrágico con hemiplejía derecha ocurrido en febrero de 2025. Debido a esto, se observa que sufre de una espasticidad moderada en el hemicuerpo derecho, mano derecha en flexión permanente con pobre apertura voluntaria. Además, requiere de un bastón de cuatro apoyos para poder desplazarse.

Teniendo en cuenta su diagnóstico, una de las necesidades principales que se puede identificar es favorecer la funcionalidad y movilidad de la mano derecha, que era su mano dominante. Actualmente la mano derecha permanece en flexión permanente y presenta pobre apertura voluntaria, lo que le impide realizar sus actividades diarias como alimentarse, asearse o vestirse por sí sola. Esto provoca una pérdida de autonomía en las actividades de su vida diaria y mayor dependencia de la familia.

El ACV es la segunda causa principal de muerte y la tercera causa principal en generar una discapacidad y muerte [1]. Además, los pacientes pueden ver afectada la funcionalidad de su extremidad superior desde el 55% hasta un 75% entre los 3 y 6 meses después de sufrir un ACV. Por esta razón, es importante la rehabilitación de los miembros afectados o, como en el caso del paciente, realizar el entrenamiento de su mano no afecta como dominante [2]. En un estudio se demostró que los factores asociados a una peor calidad de vida y capacidad funcional al mes de haber sufrido un ACV son: vivir en una vivienda diferente, una peor capacidad cognitiva y una peor capacidad funcional del miembro superior afectado. Asimismo, se afirmó la relación directa de la funcionalidad con la afectación neurológica derivada de la lesión y la disminución de la calidad de vida en la mayoría de casos de ACV [1].
Teniendo en cuenta que el reentrenamiento de su mano derecha es un proceso a largo plazo y de recuperación parcial que no se encuentra cubierta esta rehabilitación por parte de su seguro social, nos centraremos en cumplir ciertos objetivos específicos que contribuirán a la recuperación de su autonomía, independencia y calidad de vida.
Se buscará reducir la espasticidad, mejorar su capacidad de precisión básica (sostener y soltar objetos) y favorecer su independencia en al menos 3 actividades diarias(comer,asearse o escribir). Estas intervenciones reducirían la carga de cuidado familiar y favorecen una reintegración social más activa.

BÚSQUEDA DE PATENTES
1. Patente 1 [3]
- Número de patente / Publicación: US11141341B2
- Título: System and method for stroke rehabilitation using position feedback based exoskeleton control introduction
- Inventores: Eleni KOLTZI, (https://patents.google.com/?inventor=Eleni+KOLTZI&peid=63f846a11a088%3A62%3A55f6c09b) Dimitrios Tzovaras, Ioannis KOSTAVELIS, Paschalis SIDERIDIS, (https://patents.google.com/patent/US11141341B2/en#) Konstantinos PILIOUNIS. (https://patents.google.com/?inventor=Konstantinos+PILIOUNIS&peid=63f846a1d8f38%3A63%3Aeafbd38a)
- Año de publicación: 2019
- Entidad solicitante: individual
- Resumen funcional: Es un sistema de rehabilitación de manos basado en un guante doble (un guante control colocado en la mano sana que captura ángulos y movimientos de los dedos, esos datos se transmiten a un exoskeleton-glove que está ubicado en la mano afectada, que aportará la fuerza suplementaria necesaria para que la mano dañada reduzca los moví de la mano sana.
- Aspectos innovadores:
- Usa un sistema dual (control + exoskeleton), va más allá de la terapia espejo visual: reproduce posición y brinda asistencia solo cuando la mano afectada no alcanza la posición deseada.
- Algoritmo que compara la posición que se desea vs la actual por dedo y aplica esfuerzo progresivo.
- Modularidad de actuadores y la posibilidad de registro de datos para el seguimiento clínico.
- Limitaciones o vacíos:
- Está diseñado para restaurar movimiento en la mano afectada, dejando a un lado la mano sana.
- La dificultad de uso en pacientes con espasticidad severa o contractura fija.
- Elevado costo y complejidad técnica frente a dispositivos pasivos.
- Relación con la necesidad: La patente responde a la necesidad de la paciente al favorecer la movilización asistida de la mano derecha (afectada) por el ACV, ayudando a reducir espasticidad, recuperar apertura y cierre, y mejorar la autonomía para actividades cotidianas.

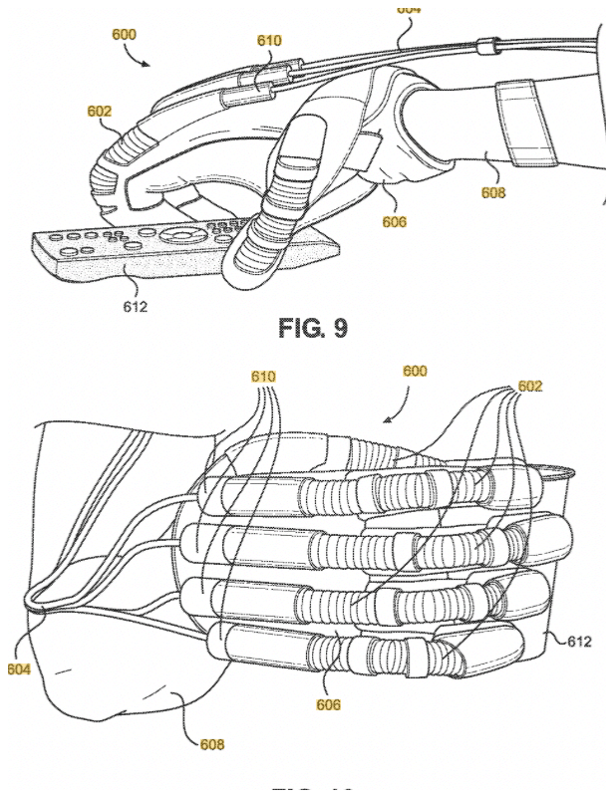
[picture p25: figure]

2. Patente 2 [4]

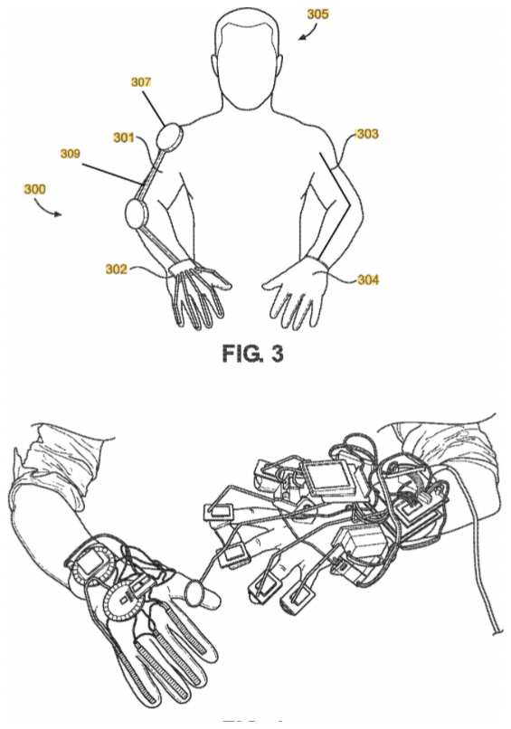
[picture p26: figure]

- Número de patente / Publicación: CN112089427A

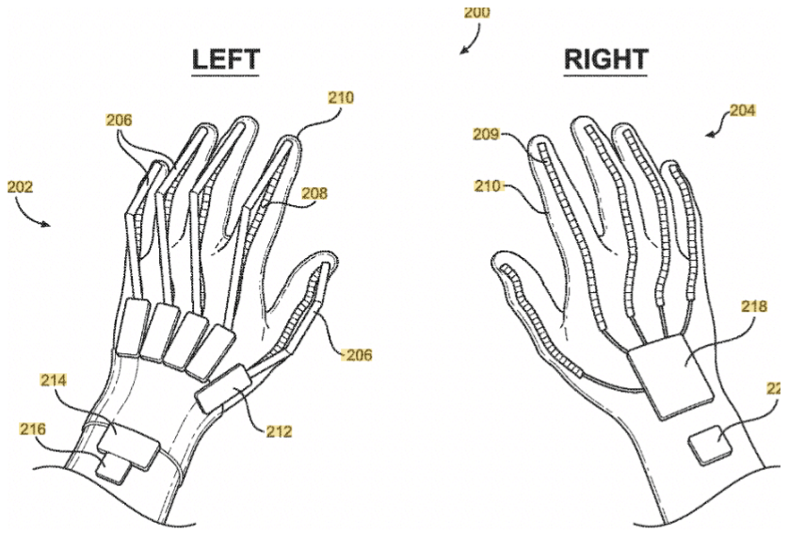
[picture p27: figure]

- Título: Finger joint rehabilitation training evaluation method and system
- Inventores: 杨瑞嘉, 史志怀, 袁路林, 陈彬, 苗盛巍
- Año de publicación: 2020
- Entidad solicitante: Nanjing Medical Technology Co ltd Nanjing Ruishide Medical Technology Co ltd
- Resumen funcional: Este método se basa en guantes suaves con estructuras neumáticas en las articulaciones de los dedos para realizar un seguimiento de alta precisión de los movimientos de la mano. Se diseñan diferentes métodos de rehabilitación para mejorar la movilidad en pacientes con hemiplejia, combinando entrenamientos activos y pasivos, además de evaluar la fuerza muscular y la función de la mano.
- Aspectos innovadores: El enfoque innovador incluye el uso de guantes suaves con control neumático para rehabilitar las articulaciones de los dedos, acompañado de un sistema de captura de movimiento óptico basado en visión binocular para medir el rango de movimiento de las articulaciones y la muñeca. También se incorporan sensores de fuerza de agarre y pellizco para evaluar la función muscular.
- Limitaciones o vacíos: La rehabilitación robótica y los dispositivos de asistencia, como los guantes neumáticos descritos, suelen ser costosos y no están disponibles en la mayoría de los sistemas de salud pública, especialmente en países de ingresos bajos y medianos. Esto limita su implementación en comunidades con recursos limitados.
- Relación con la necesidad: Este método responde a la necesidad de mejorar la rehabilitación de la mano en pacientes hemipléjicos, ofreciendo un entrenamiento personalizado y medido con base en datos precisos, lo que puede mejorar la calidad de vida de estos pacientes al recuperar funciones motoras.

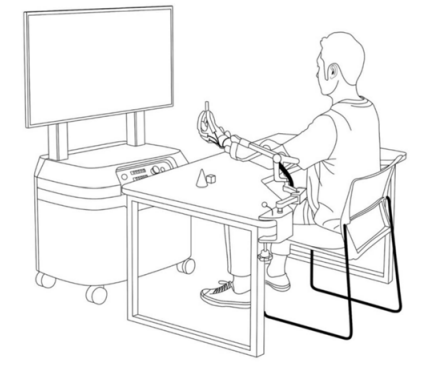
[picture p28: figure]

3. Patente 3 [5]

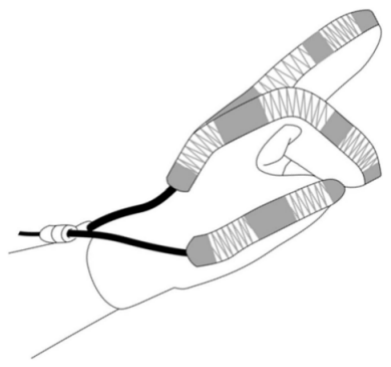
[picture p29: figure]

- Número de patente / Publicación: US 11,696,704 B1/Jul. 11, 2023
- Título: System, device and method for tracking the human hand for upper extremity therapy
- Inventores: Richard J. Adams, Connor W. Adams, William T. Gresick, Matthew D. Lichter, Aaron B. Olowin
- Año de publicación: 2023
- Entidad solicitante: Barron Associates, Inc.
- Resumen funcional: Es un dispositivo portátil que se monta en la mano mediante clips/soportes ligeros con sensores integrados. Estos registran en tiempo real los movimientos o intentos de movimiento de los dedos y la mano, procesándolos en datos clínicamente útiles.

El dispositivo se conecta a un software interactivo que guía ejercicios personalizados, brinda retroalimentación inmediata y almacena el progreso del paciente.
- Aspectos innovadores:
- Uso de módulos portátiles y ligeros que se acoplan a la mano sin necesidad de un guante completo
- Sensores capaces de registrar movimientos e intentos de movimiento en tiempo real
- Circuito de interpretación que traduce señales en información útil para la terapia
- Conexión con software interactivo que guía ejercicios personalizados
- Retroalimentación inmediata y registro del progreso clínico del paciente
- Limitaciones o vacíos:
- Solo registra y monitoriza movimientos, no asiste físicamente la apertura o cierre de la mano
- Requiere que exista un grado de movilidad mínimo
- Precisión depende de una buena colocación de los sensores
- Relación con la necesidad:
La paciente requiere rehabilitar su mano dañada tras el ACV, la cual mantiene espasticidad y limitada apertura voluntaria. La patente responde a esta necesidad al registrar incluso pequeños intentos de movimiento en la mano y transformarlos en datos útiles para realizar ejercicios terapéuticos interactivos. De esta forma, promueve la repetición y la retroalimentación inmediata, elemento clave para la recuperación motora. Sin embargo, no promueve asistencia mecánica activa, su efectividad depende de que la paciente conserve cierto grado de movilidad voluntaria.

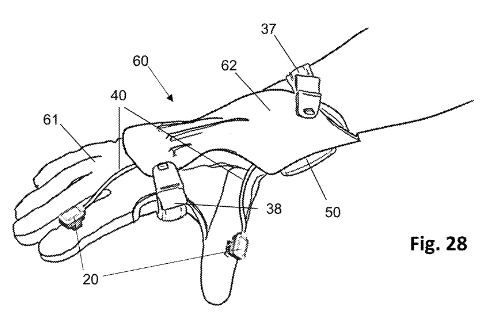
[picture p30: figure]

4. Patente 4 [6]

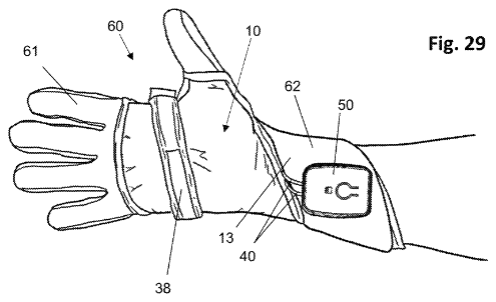
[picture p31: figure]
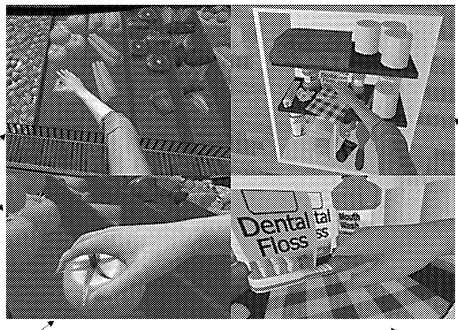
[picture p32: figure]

- Número de patente / Publicación: WO2008131563A1
- Título: Robotic exoskeleton for limb movement
- Inventores: Stephen. H. Scott, Ian E. Brown, Stephen J. Ball
- Año de publicación: 2008
- Entidad solicitante: Universidad Queen´s de Kingston
- Resumen funcional: Es una invención que comprende un exoesqueleto robótico que utiliza enlaces mecánicos con articulaciones seleccionadas en la extremidad de un paciente.
- Aspectos innovadores: La recopilación de datos respecto al ángulo de la posición en el que es puesto, aceleración o torque, es bastante útil para el estudio del progreso del paciente con esa información, además puede ayudar tanto con el diagnóstico como tratamiento a largo plazo de una deficiencia sensorial-motora en una extremidad
- Limitaciones o vacíos: Los ejes que proponen como innovadores “Ejes virtuales” entre las articulaciones y la parte mecánica del exoesqueleto aún corren riesgo de desalinearse.
- Relación con la necesidad: Al ser un exoesqueleto enfocado en una extremidad (en este caso brazo ) sería de gran ayuda para de alguna manera incentivar el movimiento y/o rehabilitación de la extremidad en cuestión, además, se recolectarán datos cruciales para evaluaciones de la paciente y de esta manera asegurarse de tener en cuenta el estado de movilidad para realizar un plan integral de terapia.


5. Patente 5 [7]
- Número de patente / Publicación: US11246786B2 / Feb.15,2022

- Título: POWER ASSISTIVE DEVICE FOR HAND REHABILITATION AND A METHOD OF USING THE SAME
- Inventores: Kam Fai Michael Tsui; Haris Begovic; Pui Yung Tsui; Wai Chiu Or y Pak Hin Leung
- Año de publicación: 15 de febrero de 2022
- Entidad solicitante: Rehab - Robotics Company
- Resumen funcional:
Es un sistema asistido para la rehabilitación de la mano que combina una férula equipada con actuadores y sensores y una base que soporta el antebrazo. Además, utiliza señales electromiográficas y sensores de fuerza en los dedos para detectar la intención y el esfuerzo del paciente, lo que permite generar movimientos coordinados de flexión-extensión de los dedos y supinación-pronación del antebrazo. De esta manera, se busca facilitar la medición del progreso y el apoyo en pacientes con limitaciones motoras tras un ACV.
- Aspectos innovadores:
1. Entrenamiento combinado en múltiples grados de libertad, incorpora movimientos de los dedos y el antebrazo.
2. Uso de EMG + force sensors para detectar intención de movimiento y medir fuerza, y sincronizar el dispositivo con estos datos.
3. Diseño ajustable/modular, la férula tiene componentes ajustables para diferentes tamaños de palma, los actuadores están alineados para reducir estrés en la muñeca, la plataforma rotatoria tiene rangos definidos.
4. Capacidad de control mediante dispositivo portátil (smartphone, tablet, etc.) para almacenar historial y visualizar resultados.
- Limitaciones o vacíos:
1. Al tener múltiples sensores, fabricación, mantenimiento y calibración pueden resultar costosos. No está descrito con detalle el costo ni análisis de viabilidad en entornos con pocos recursos.
2. La patente describe la invención y ejemplos de operación, pero no reporta validación clínica, ni evidencias de uso real, ni ensayos clínicos con pacientes con ACV.
3. No queda completamente claro cuán eficaz es este dispositivo si el paciente tiene daño severo o muy poca capacidad motora residual. La patente describe detención de fuerza y sincronización, pero no detalla adaptaciones específicas para esos casos.
- Relación con la necesidad:
Esta patente se relaciona bastante con la necesidad del paciente con ACV, pues muchas veces se pierde la capacidad de flexión/extensión de los dedos. Un dispositivo que entrene ambos movimientos de forma combinada puede ayudar a recuperar la funcionalidad.


REFLEXIÓN

Las tecnologías analizadas muestran avances significativos en la rehabilitación de pacientes post-ACV, sin embargo, presentan limitaciones que dificultan su aplicación en todos los contextos. Un aspecto que debe considerarse en un nuevo prototipo es la accesibilidad, tanto en términos de costo como de facilidad de uso, con un diseño portátil y adaptable que permita su implementación en el hogar sin necesidad de equipos de gran tamaño o de personal altamente especializado. También resulta importante que el prototipo incluya retroalimentación inmediata y la posibilidad de registrar el progreso del paciente, favoreciendo un seguimiento continuo y personalizado de la rehabilitación. La necesidad de favorecer la funcionalidad de la mano derecha en pacientes con ACV no sólo revela un desafío clínico, sino también una oportunidad de innovación tecnológica.
La escasez de dispositivos adaptados en los sistemas de salud públicos y la dependencia de la importación de tecnologías costosas resaltan la importancia de diseñar soluciones locales, accesibles y de bajo costo, que respondan a las realidades sociales y económicas de los pacientes y sus familias.

BIBLIOGRAFÍA
[1] G.-Santos, J., P. Rodríguez-Fernández, R. Pardo-Hernández, J. J. González-Bernal, J. Fernández-Solana, y M. Santamaría-Peláez, “A Cross-Sectional Study: Determining Factors of Functional Independence and Quality of Life of Patients One Month after Having Suffered a Stroke,” Int. J. Environ. Res. Public Health, vol. 20, no. 2, art. 995, 2023, doi: 10.3390/ijerph20020995
[2] Wodu C. O.; Sweeney G.; Slachetka M.; Kerr A., “Stroke Survivors’ Interaction With Hand Rehabilitation Devices: Observational Study,” JMIR Biomedical Engineering, vol. 9, art. e54159, 26-Jun-2024, doi: 10.2196/54159.

[3]E. Koltzi, D. Tzovaras, I. Kostavelis, P. Sideridis y K. Piliounis, “System and method for stroke rehabilitation using position feedback based exoskeleton control,” US 11,141,341 B2, publicada 12 de octubre de 2021.

[4] Y. Rui Jia, S. Zhi Huai, Y. Lu Lin, C. Bin, M. Sheng Wei, "Finger joint rehabilitation training
evaluation | method | and | system," | CN112089427A, | 2020. | [Online]. | Available:
https://patents.google.com/patent/CN112089427A/en
[5] R. J. Adams, C. M. Westbrook, y C. W. Olinger, “System, device and method for tracking the human hand,” U.S. Patent 11,696,704 B1, Jul. 11, 2023.
[6] Stephen H, et al. “Robotic exoskeleton for limb movement” Patente WO2008131563A1, 30 oct. 2008.
[7] K. F. M. Tsui, H. Begovic, P. Y. Tsui, W. C. Or, and P. H. Leung, “Power assistive device for hand rehabilitation and a method of using the same,” U.S. Patent 11,246,786 B2, Feb. 15, 2022.

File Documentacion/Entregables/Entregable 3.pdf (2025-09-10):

# ENTREGABLE 3

### Integrantes: Carla Ulloa Florián Nahir Valladares Santur Luciana Vega Llanos Carla Victoria Quispe Stela Villagomez Altamirano Almendra Yataco Diaz

### Profesor: Juan Manuel Zuñiga

### Curso: Fundamentos de Biodiseño

2025

### ACCIDENTE CEREBROVASCULAR (ACV)

### 1. FICHA DE LA ENFERMEDAD

Sistema afectado: Sistema nervioso central (SNC)
Breve descripción anatómica/fisiológica: Sucede cuando el flujo de sangre al cerebro queda bloqueado o cuando se produce un sangrado repentino en el cerebro. Como consecuencia, el cerebro no recibe oxígeno ni nutrientes de la sangre, debido a ellos las células cerebrales comienzan a morir, creando un daño cerebral permanente, discapacidad a largo plazo o la muerte. Se divide en dos tipos: accidente cerebrovascular isquémico e infarto cerebral [1].

### 2. FACTORES Y ANÁLISIS DE LA ENFERMEDAD

Factores de riesgo principales [2]:
- Edad: Más común en bebés de menos de 1 año y adultos mayores
- Niveles elevados de estrés: Trabajar muchas horas, falta de contacto familiar, etc
- Antecedentes familiares: Asociado a los genes familiares
- Vivir en zonas con contaminación: La calidad del aire puede influir
- Hábitos poco saludables: Inactividad física, dieta pobre, tabaquismo, alcoholismo, drogas, etc
- Sexo: A temprana edad, los hombres son más propensos a padecer ACV, mientras que las mujeres embarazadas y/o consumen anticonceptivos tienen un riesgo mayor.

Manifestaciones clínicas más relevantes
Según tipos de ACV:
❖ ACV isquémico [3]
El ACV isquémico ocurre cuando una arteria cerebral se obstruye parcial o totalmente, reduciendo o bloqueando el flujo sanguíneo al cerebro. Representa alrededor del 80–85 % de todos los ACV.
➔ Inicio abrupto de deterioro neurológico focal: El evento se caracteriza por un déficit neurológico súbito que afecta de manera localizada determinadas funciones del sistema nervioso, según el territorio vascular comprometido.
➔ Alteraciones sensoriales: pérdida de sensibilidad en zona contralateral al daño.

Mecanismos del ACV isquémico

1.- Trombosis in situ

- Formación de un coágulo directamente en una arteria cerebral previamente dañada por aterosclerosis.
- Suele ocurrir en arterias grandes como la carótida interna o la cerebral media.
- Relacionado con factores de riesgo como hipertensión, diabetes, dislipidemia y tabaquismo.

2.-Embolismo

- Un coágulo o fragmento de placa aterosclerótica se desprende desde otra parte del cuerpo y viaja hasta el cerebro.
- Orígenes comunes:
1. Cardioembólico: Fibrilación auricular, infarto de miocardio reciente, miocardiopatías,etc.
2. Arterio-arterial: Fragmentos que se desprenden de placas ateroscleróticas.

3.-Lacunar o enfermedad de pequeños vasos

- Ocurre por lipohialinosis o microateromas que obstruyen arterias perforantes profundas.

- Asociado a hipertensión crónica y diabetes.

4.-Hipoperfusión hemodinámica

- Disminución global del flujo sanguíneo cerebral, por ejemplo en casos de hipotensión severa , shock o estenosis críticas de grandes arterias

❖ ACV hemorrágico [4]
El ACV hemorrágico ocurre cuando un vaso sanguíneo cerebral se rompe, provocando sangrado dentro del cerebro (hemorragia intracerebral) o en el espacio entre el cerebro y las meninges (hemorragia subaracnoidea).
➔ Cefalea intensa y súbita
➔ Náuseas y vómitos
➔ Convulsiones
➔ Alteración de nivel de consciencia Mecanismos de ACV hemorrágico
1.-Hemorragia intracerebral (HIC): ruptura de un vaso sanguíneo dentro del parénquima cerebral, lo que genera un hematoma.
- Hipertensión arterial crónica: causa degeneración de pequeñas arterias perforantes (lipohialinosis, microaneurismas de Charcot-Bouchard).
- Amiloidosis cerebral: depósito de β-amiloide en la pared de pequeños vasos, frecuente en mayores de 70 años.

2.-Hemorragia subaracnoidea (HSA): sangrado en el espacio subaracnoideo, donde circula el líquido cefalorraquídeo.
- Traumatismo craneoencefálico.
- Malformaciones arteriovenosas (MAV)
- Disecciones arteriales o angiopatía amiloide en raros casos.

Impacto funcional en la vida diaria [5] [6]
- Dependencia temprana en AVD (actividades básicas de la vida diaria)
a. Hasta el 60 % de los pacientes presentan dependencia en actividades básicas de la vida diaria (AVD) en los primeros dos días tras el ACV.
b. Aproximadamente un 35 % de los sobrevivientes mantienen dependencia en AVD al cumplirse un año.
- Impacto psicológico y social
a. La dependencia sostenida genera mayor carga para cuidadores, incremento del aislamiento social y deterioro de la calidad de vida.
b. Depresión, ansiedad y apatía post-ACV son frecuentes y se asocian a peor calidad de vida.
- Pérdida motora tras ACV
a. Hemiparesia o hemiplejía (debilidad/parálisis en un lado del cuerpo)
- Dificultad para tragar (disfagia)
a. Frecuencia: Presente en alrededor de 50 % de los pacientes en fase aguda.
b. Un subgrupo (~10 %) mantenía problemas persistentes de deglución a largo plazo, aumentando el riesgo de complicaciones como neumonía aspirativa y malnutrición.

### 3. PREVENCIÓN, DIAGNÓSTICO, TRATAMIENTO Y MONITOREO

Prevención: [7]
Requiere una combinación de hábitos de vida saludable:
- Controlar la presión arterial alta y la diabetes
- Reducir la cantidad de colesterol y grasas saturadas, ayuda a reducir la acumulación en las arterias.
- Hacer ejercicio con regularidad, como caminar, nadar y andar en bicicleta.
- Ingerir bebidas alcohólicas con moderación y no hacer uso de drogas ilícitas, porque afectan la presión y la circulación.
- Mantener una alimentación con abundantes frutas y verduras
- Tomar medicamentos preventivos, tales como antiplaquetarios y anticoagulantes

Diagnóstico:
- Para el diagnóstico de ACV se necesita de una evolución urgente, rápida y precisa. Lo primero es registrar la hora en el que los síntomas se presentan, es decir, la última vez visto bien (LKV), y aplicar la NIH Stroe Scale (NIHSS) para medir la gravedad neurológica [8]. El estudio de imágenes inicial preferible es la tomografía computarizada (TC) de cráneo sin contraste, para poder diferenciar entre un ACV isquémico de un hemorrágico. En algunos casos se acompaña con un angio-TC, también llamado resonancia magnética de difusión (RM-DWI) para poder localizar obstrucciones de vasos sanguíneos y valorar tejido cerebral recuperable [9]. Por otro lado, se requieren de análisis de laboratorio, como glucosa, hemograma, función renal y coagulación, y electrocardiograma (ECG) para eliminar efectos como fibrilación auricular y conocer la seguridad de tratamientos como la trombolisis [10].

Tratamiento:
- Farmacológico: [11]
- Trombólisis (rtPA) y Anticoagulantes: Estos tratamientos se aplican principalmente a ACV isquémico. Se utiliza para disolver los coágulos que bloquean el flujo sanguíneo hacia el cerebro. Este medicamento debe administrarse dentro de las primeras 3-4.5 horas tras el inicio del ACV para ser efectivo.
- DM199: Se están explorando nuevas opciones terapéuticas, como DM199, una forma recombinante de una proteína natural llamada kallikrein-1, que ha mostrado resultados prometedores en el tratamiento del ACV con menos efectos secundarios.
- Anticoagulantes: En algunos casos, como en el ACV isquémico por fibrilación auricular, se recetan medicamentos como la warfarina o nuevos anticoagulantes orales.
- Células madre: Se están evaluando terapias celulares con células madre como opciones potenciales para mejorar la recuperación post-ACV y restaurar la plasticidad cerebral.
- Quirúrgico:
- Craneotomía descompresiva: En casos de ACV hemorrágico en la región cerebelosa, una craneotomía descompresiva puede ser beneficiosa para aliviar la presión intracraneal. [12]
- Rehabilitación:
- Terapia física: Ayuda a recuperar el movimiento y la función motora, especialmente si hubo parálisis o debilidad en alguna parte del cuerpo. [13]
- Neurorestauración: Capacidad del cerebro para reorganizarse, formar nuevas conexiones neuronales y, en algunos casos, recuperar funciones que se habían perdido a causa del daño cerebral. Esto se logra combinando diferentes técnicas y enfoques fisioterapéuticos como el ejercicio terapéutico, la estimulación sensorial, la movilización de las extremidades, entre otros, que ayudan a mejorar tanto el equilibrio como la funcionalidad del paciente. [13]
- Terapia ocupacional: Para mejorar la capacidad de realizar actividades diarias, como vestirse o cocinar.
- Terapéutico:
- Exosomas: Han atraído la atención por su capacidad para cruzar la barrera hematoencefálica y su potencial terapéutico. Estas vesículas contienen miARNs, proteínas y otros componentes celulares que pueden influir en la reparación neuronal y la neuroprotección después de un ACV. [14]
■ En ACV isquémico: Pueden tener efectos neuroprotectores y ayudar en la reparación neuronal. Se están utilizando como biomarcadores no invasivos para el diagnóstico temprano y la predicción del pronóstico.
■ En ACV hemorrágico: Aunque menos comunes, los exosomas también pueden actuar como biomarcadores para el diagnóstico y seguimiento, al facilitar la monitorización de los efectos del daño cerebral.

Monitoreo:
- Seguimiento clínico:
- Control médico: Las visitas periódicas al médico son esenciales para monitorear la recuperación del paciente tras un ACV. Esto incluye evaluar la evolución del paciente, la aparición de posibles complicaciones y ajustar el tratamiento según sea necesario. Este seguimiento puede ser realizado por un neurólogo y otros especialistas en función de los síntomas y el tratamiento recibido.
- Monitorización de la presión arterial: Es fundamental mantener la presión arterial bajo control para prevenir un nuevo evento cerebrovascular. Se recomienda que los pacientes con antecedentes de ACV se sometan a chequeos regulares de su presión arterial, especialmente durante las primeras semanas y meses después del evento.
- Seguimiento neurológico: Se debe realizar un seguimiento neurológico continuo para evaluar la posible aparición de complicaciones a largo plazo. Estas pueden incluir problemas cognitivos, déficits motores, dificultades en el habla o trastornos del comportamiento.
- Pruebas periódicas:
- Tomografía computarizada (TC) o resonancia magnética (RM): Son técnicas de imagen esenciales para evaluar el daño cerebral tras un ACV y monitorear su evolución. La RM es particularmente útil para identificar infartos cerebrales pequeños y evaluar la extensión de las lesiones a lo largo del tiempo, mientras que la TC es preferida para evaluar situaciones agudas y descartar hemorragias cerebrales. [15]

### 4. REFLEXIÓN INGENIERIL

El ACV plantea retos significativos en lo concierne a su tratamiento. El paciente con ACV principalmente presenta dificultades en su motricidad lo que incluso genera al paciente dificultad para poder realizar sus actividades cotidianas , puede llegar a vivir durante décadas con esta enfermedad, por lo que exige el desarrollo de soluciones tecnológicas no solo funcionales en la movilidad y la autonomía de los pacientes en sus actividades cotidianas, sino también en su calidad de vida, reduciendo fatiga, facilitando su monitoreo continuo e inclusión social. En este contexto, se busca integrar conocimientos médicos y tecnológicos para buscar soluciones, la dignidad e integridad del paciente.

ENTENDIENDO AL USUARIO II
CASO 1 [16]
Un hombre de 77 años sufrió un accidente cerebrovascular en el hemisferio izquierdo con hemiparesia derecha. Teniendo consecuencias en el rendimiento de su extremidad superior derecha y en su habla, dificultando sus actividades diarias. Se implementó fisioterapia, terapia ocupacional y logopedia a diaria, orientado a tareas funcionales con el objetivo de recuperar la movilidad y mejorar la autonomía en actividades de la vida diaria.

### 1. Relevancia para el análisis

El caso clínico seleccionado es relevante para el análisis porque describe el proceso de recuperación de un paciente con hemiparesia posterior a un accidente cerebrovascular, el cual logró recuperar su funcionalidad en brazo y mano para realizar tareas de la vida diaria. Teniendo en cuenta este caso, se puede analizar detalladamente el tratamiento con el que recuperó su independencia funcional. Este estudio abarcó procesos importantes al momento de cuantificar el progreso, utilizando escalas clínicas como Fugl-Meyer y parámetros de escritura, procesos que podrían ser necesarios durante la elaboración de la solución para nuestra paciente. Además, el paciente, al igual que nuestro caso, sufrió un ACV y perdió funcionalidad en su mano derecha, es decir, comparten necesidades. Por último, el caso describe un tratamiento que también podría aplicarse a nuestra paciente; por lo tanto, se puede usar como referencia para el diseño de un dispositivo que satisfaga sus necesidades.

### 2. Perfil funcional

Habilidades conservadas:
- conservaba movilidad parcial en hombro y codo (proximal)
Limitaciones
- debilidad en la extremidad superior derecha
- dificultad para mantenerse de pie y caminar
- boca parcialmente paralizada, lo que le dificultaba el habla (parálisis flácida)
- control distal de la muñeca y los dedos estaba gravemente afectado

Escala clínicas:
En el caso clínico, se emplearon las siguientes técnicas
- Fugl-Meyer (FM): escala estandarizada que evalúa la función motora del brazo y la mano tras un ACV. En el caso clínico se realizó para observar la mejoría tras el tratamiento [17]
- Medición de parámetros de escritura: Evaluó la velocidad de escritura como indicador funcional de destreza manual [16].
- Electromiográfica (EMG): Evaluar la actividad muscular [16]

### 3. Mapa de actividades críticas

Vida diaria: El paciente antes del ACV era un hombre que desde los 20 años trabaja pero que con la edad se enfocó en trabajos administrativos en el taller. Sin embargo, después del ACV:
- No podía vestirse de forma independiente,
- No podía atender sus propias necesidades
- No podía alimentarse por sí solo
- boca parcialmente paralizada, dificultando su comunicación

Con la información recolectada podemos afirmar que:
- Nivel de independencia: Baja
- Dificultades principales: Dificultades en actividades de la vida diaria (AVD) debido a su poco movilidad en su muñeca y mano

- Impacto en la calidad de vida: El paciente pasó a depender de su familia puesto que requiere ayuda para hacer las tareas diarias como comer, vestirse, etc. Además, no poder comunicarse adecuadamente, dificulta su calidad de vida y autonomía personal.

Laborales: El paciente, debido a su edad, se limitaba a realizar trabajos administrativos en el taller; sin embargo, con el ACV se vio restringido incluso de trabajos administrativos ya que sus limitaciones funcionales como dificultades para mover la mano o lentitud de escritura, se lo impiden.
- Nivel de independencia: Baja
- Dificultades principales: Déficit motor en muñeca y mano, bajo control de movimientos finos, dificultad para manipular objetos pequeños y escritura lenta
- Impacto en la calidad de vida: El no poder volver a trabajar redujo sus oportunidades de interacción social y le se creó la sensación de ser menos productivo, afectando su autoestima y su ánimo.

Rehabilitación: El paciente participó en un programa de entrenamiento orientado a tareas enfocado en la recuperación de la función del brazo y la mano. Este consistió en la práctica repetitiva de actividades funcionales, como agarrar y soltar latas, manipular objetos y realizar ejercicios de escritura. El progreso del paciente era evaluado mediante la escala Fugl-Meyer y parámetros objetivos de escritura.
- Nivel de independencia: Antes del tratamiento, el paciente tenía un nivel de independencia bajo, con limitaciones para realizar movimientos finos de la mano y la muñeca. Después del tratamiento, logró mejorar de manera significativa, alcanzando mayor control motor y destreza.
- Dificultades principales: El paciente presentaba limitaciones en la movilidad distal de la mano y los dedos, con dificultad para realizar movimientos finos y coordinar la prensión. La escritura era lenta y poco funcional al inicio del tratamiento
- Impacto en la calidad de vida: La rehabilitación permitió al paciente recuperar parte de su autonomía, mejorar la escritura y desenvolverse con mayor independencia en sus actividades diarias

### 4. Barreras y facilitadores

- Barreras:
- La falta de atención médica especializada en los primeros indicios de la enfermedad , cuando sufría debilidad en el lado derecho del cuerpo y la cara, así como problemas de habla, al no revelar nada la tomografía y presentar una leve mejora motora fue regresado a su hogar sin tratamiento o métodos de prevención para sus síntomas.
- Diagnosticada la enfermedad el hospital contaba con escasos servicios de fisioterapia o rehabilitación, recién pudo recibir tratamiento de rehabilitación en el centro geriatrico.
- En las etapas iniciales del tratamiento , el paciente presentó incapacidad funcional en el brazo derecho, con movimientos distales (como muñeca y dedos) severamente comprometidos, lo que ocasionaba dificultad para realizar sus actividades básicas como alimentarse o vestirse.
- Facilitadores:
- Logró recibir fisioterapia, terapia ocupacional y logopedia a diario, con énfasis en el entrenamiento orientado a tareas en el centro geriatrico.

- El protocolo de rehabilitación aceptado logró evaluar un tratamiento especializado en los aspectos que se debían mejorar y funciones que rehabilitar como la función motora de las extremidades superiores del paciente, tanto a nivel de deterioro como de discapacidad.
- Tuvo acceso a varios tipos de evaluaciones, pues de la función motora se realizaron dos veces: al ingreso (T1) y al alta (T2). Se incluyeron tres herramientas de medición: la parte motora de las extremidades superiores de la escala de evaluación Fugl-Meyer (FM), electromiografía (EMG) para alcanzar la mano, prender y manipular objetos, y tareas de escritura.
- Los ejercicios que realizaba incluían actividades cotidianas las variaciones en objetos (tamaño, peso, textura) , las repeticiones frecuentes (aproximadamente 200 por sesión de una hora) y el entorno variable promovieron retención y transferencia de habilidades motoras mejorando de esta forma su tratamiento.
- El enfoque en su tratamiento estuvo guiada y especializada en mejorar la motricidad para realizar actividades cotidianas, la fisioterapia y la terapia ocupacional trataron la práctica de las actividades diarias mientras que la terapia ocupacional se centró en las funciones de las extremidades superiores, como la alimentación, vestirse y usar objetos con las manos, la fisioterapia se centró en la locomoción, caminar, subir escaleras, equilibrio y transferencias, todas sus sesiones de tratamiento fueron construidas con base en los principios fundamentales del aprendizaje motor [16]
- el terapeuta diseñó cada ejercicio para minimizar el uso de estrategias de compensación. el terapeuta proporcionó retroalimentación sobre los resultados con enfoque externo, 27 (https://pmc.ncbi.nlm.nih.gov/articles/PMC5372193/?utm_source=chatgpt.com#R27) pidiéndole al paciente que siguiera una trayectoria recta guiada por cinta adhesiva sobre la mesa. Se ha reportado previamente que la retroalimentación centrada en factores externos mejora el rendimiento motor en otros contextos y también en la automatización de habilidades. [16]

### 5. Mapa de dolor (Pain Points)

- Impotencia:
Le generaba impotencia :
- La Imposibilidad de mover el brazo y la mano derecha tras el ACV.
- Incapacidad para realizar actividades cotidianas y básicas como comer, vestirse o escribir.
- Su pérdida de autonomía, generando frustración y sentimientos de inutilidad.
- Falta de acceso a su rehabilitación:
- Los primeros 10 días post-ictus recibió mínima fisioterapia en el hospital general.
- Retraso en el inicio de un entrenamiento orientado a tareas, clave en la recuperación.
- Déficit motor :
- Limitaciones persistentes para actividades de la vida diaria que requieren precisión.
- Impacto emocional y psicológico
- Ansiedad y frustración al no poder reincorporarse rápidamente a sus actividades habituales.
- Sentimiento de carga hacia la familia.
- Necesidad de acompañamiento constante para actividades simples

### 6. Expectativas del usuario

Dentro de las expectativas del paciente espera principalmente recuperar la autonomía en sus actividades diarias, recuperar su motricidad y mejorar la movilidad del brazo y la mano afectados, reincorporarse a sus roles familiares y sociales, recibir un tratamiento efectivo y continuo que le permitiera practicar también fuera del hospital, contar con el acompañamiento de su familia y del equipo terapéutico durante todo el proceso, y finalmente mejorar su calidad de vida al disminuir la dependencia, recuperar seguridad en sí mismo y retomar la confianza en su futuro después del ictus.

CASO 2 [18]
Una señora de 83 años de edad llegó a mostrar una pérdida de las funciones de un solo ojo de forma inesperada y sin dolor. La angio-TC mostró una obstrucción de la carótida interna, por lo que se le administró trombolisis intravenosa dentro de las primeras horas para intentar el restablecimiento del flujo sanguíneo. Después de eso una evaluación de flujo sanguíneo cerebral evidenció un bloqueo en la arteria cerebral media, llevando a cabo una trombectomía mecánica que permitió que el flujo sanguíneo siga de manera satisfactoria. Al darle de alta a la paciente no llegó a presentar déficit funcional y recuperó su capacidad de hacer sus actividades en la vida cotidiana.

### 1. Relevancia para el análisis

El caso es relevante porque muestra cómo un ACV puede presentarse con síntomas poco comunes (pérdida visual súbita) y cómo el diagnóstico temprano y la intervención combinada logran una recuperación funcional, incluso en pacientes mayores.

### 2. Perfil funcional

- Diagnóstico:
Oclusión de arteria carótida interna con extensión a arteria cerebral media
- Tratamiento:
Trombolisis intravenosa y trombectomía mecánica exitosa.
- Estado general:
Previamente independiente en sus actividades
Inicio súbito de pérdida visual monocular indolora
- Movilidad :
Intacta, no tiene limitaciones para caminar ni moverse.
- Funciones cognitivas:
Conservadas, manteniendo la orientación, memoria y la atención de forma correcta
- Funciones sensoriales:
Recuperada visión en el ojo, afectado tras tratamiento.
- Rehabilitación:
No requiere asistencia post-alta debido a que tuvo una recuperación completa.

### 3. Mapa de actividades críticas

Vida diaria:

- Nivel de independencia: Total al alta
- Dificultades principales: Existe el riesgo de caídas, vigilancia estricta de factores vasculares.
- Impacto en la calidad de vida: Recuperación completa, mantiene autonomía al igual que calidad de vida.

Laborales / educativa:
- Nivel de independencia: Jubilada, sin actividad laboral o educativa activa.
- Dificultades principales: Seguimiento médico y control de causas de riesgo.
- Impacto en la calidad de vida: Evita complicaciones a largo plazo, mantiene independencia.

Rehabilitación:
- Nivel de independencia: No requiere de rehabilitación prolongada por no tener un déficit residual.
- Dificultades principales: Tener un seguimiento constante médico, al igual que causas de riesgo.
- Impacto en la calidad de vida:

Actividades terapéuticas de prevención/progresión:
- Nivel de independencia: Alta, con autocuidado supervisado.
- Dificultades principales: Cambio en el estilo de vida, además de un estricto cumplimiento en el consumo de medicación.
- Impacto en la calidad de vida: Se asegura una prevención secundaria de ACV y mayor seguridad clínica.

### 4. Barreras y facilitadores

- Barreras: Edad avanzada (tercera edad), alto riesgo cardiovascular, además de probabilidad de nuevos eventos.
- Facilitadores: Rápido acceso a diagnósticos por imagen, terapias revascularizantes efectivas, buena red de salud y adherencia al tratamiento.

### 5. Mapa de dolor (Pain Points)

- Daño emocional en las primeras etapas debido al temor a ceguera o dependencia.
- Ansiedad por el riesgo de un nuevo ACV.
- Necesidad del seguimiento constante con profesionales.

### 6. Expectativas del usuario

La paciente desea mantener su independencia, realizar sus actividades de la vida diaria y conservar una buena calidad de vida a pesar de edad. Después del alta, se espera que siga en apoyo continuo con revisiones de control que aseguren su bienestar.

CASO 3 [19]
R.S es un varón de 55 años. Antes de padecer la lesión era independiente y trabajaba en PSA. Vive con su mujer y su hijo de 2 años en un piso con ascensor. Hoy en día R.S no tiene intención de volver a trabajar ya que con un hijo de dos años quiere poder disfrutar de verle crecer y estar con él si las circunstancias son favorables y se lo permiten. Desde el año 2018 caminaba con bastón debido a una coxalgia de cadera izquierda de la cual fue intervenido y le colocaron una prótesis total de cadera. En el mes de junio de 2021 fue re-intervenido. Este dato posteriormente será relevante y para tener en cuenta debido a que presenta cierta limitación en la movilidad de esa cadera. El 18 de octubre, a las 17:50h presentó un mareo con cefalea brusca, seguido de una hemiplejia izquierda. Se activó el código ictus a las 18:15h. Ingresó en el HUMS y tras 3 días en la UCI fue trasladado a la planta de rehabilitación.

### 1. Relevancia para el análisis

Este caso clínico es acerca de una persona de la misma edad que la paciente de nuestro caso clínico, además en ambos casos se presenta hemiplejia aunque en diferentes niveles (en el presente caso caso clínico esta hemiplejía no está consolidada y existe un margen de recuperación mientras que en el caso proporcionado por los asesores la paciente tiene hemiplejía crónica). Aún así, es importante analizar ambos escenarios porque nos permite contrastar las fases del ACV y sus implicancias en el proceso de rehabilitación. En el caso actual, el abordaje se centra en la intervención temprana para favorecer la recuperación funcional y prevenir complicaciones, mientras que en el caso de la paciente con hemiplejía crónica el énfasis está en la adaptación, el manejo de secuelas y la mejora en la calidad de vida pese a las limitaciones permanentes. Esta comparación ofrece una visión integral del curso clínico de la enfermedad, destacando la importancia del tratamiento oportuno y la necesidad de ajustar los objetivos terapéuticos según la etapa en la que se encuentre el paciente.

### 2. Perfil funcional

En el documento en el que se encontró el caso clínico se utiliza la escala FIM ( Functional Independence Measure o Medida de Independencia Funcional ) y el índice de Barthel para evaluar al paciente.

- Ingreso hospitalario:
- Escala FIM : 22/126
Dependencia total
- Índice de Barthel: 5/100
Dependencia severa
- Observación inicial: hemiplejia izquierda flácida, sin movimiento voluntario, totalmente dependiente en AVD
- Mitad de intervención - 2 meses después
- FIM: 106/126
- Índice de Barthel: 70/100
- Alta hospitalaria - 5 meses después
- FIM: 118/126 (gran autonomía).

### 3. Mapa de actividades críticas

Vida diaria:
R.S es un hombre de 55 años que antes del ictus era independiente y activo en sus actividades cotidianas, incluyendo la participación en las tareas del hogar y el cuidado de su hijo pequeño. Tras el ACV hemorrágico presentó una hemiplejia izquierda que lo dejó totalmente dependiente para todas las actividades básicas de la vida diaria (alimentación, vestido, higiene, transferencias y movilidad). Con la rehabilitación multidisciplinar fue recuperando progresivamente su autonomía: el alta hospitalaria era independiente para la mayoría de las AVD básicas, aunque requería más tiempo y cierta ayuda en el vestido de la parte inferior y en la subida/bajada de escaleras. En las actividades instrumentales de la vida diaria, podía colaborar en la preparación de comidas sencillas y en algunas tareas ligeras del hogar, aunque aún necesitaba apoyo en compras grandes, uso de transporte y lavado de ropa. En general, su vida diaria está marcada por un grado de independencia funcional alto, pero con limitaciones específicas que afectan su rol familiar y doméstico.
- Nivel de independencia
- Independiente en la mayoría de AVD básicas (alimentación, aseo personal, vestido de la parte superior, transferencias y deambulación con bastón).
- Dependencia ligera en vestido de la parte inferior.
- Necesita asistencia para subir y bajar escaleras.
- Dificultades principales.
- Vestirse la parte inferior, especialmente ponerse calcetines y calzado en la pierna afectada.
- Subir y bajar escaleras, incluso pocos escalones, siempre con apoyo de otra persona.
- Marcha con riesgo de tropiezos por limitación en miembro inferior izquierdo.
- Fatiga en actividades prolongadas.
- Impacto en la calidad de vida.
- Ha recuperado gran parte de su autonomía, lo que le permite reintegrarse en la dinámica familiar.
- Las limitaciones en AVD y AIVD generan cierta dependencia de su esposa, especialmente en tareas domésticas y movilidad en exteriores.

Laborales/educativas:
Antes del ictus, R.S trabajaba en PSA y era completamente independiente en su desempeño laboral. Tras el ACV hemorrágico decidió no reincorporarse a su puesto de trabajo, ya que su prioridad actual es poder dedicar tiempo a su hijo de 2 años y adaptarse a sus nuevas capacidades.
- Nivel de independencia
- Independiente para participar en actividades educativas o de aprendizaje informal en casa.
- No se ha reincorporado al ámbito laboral formal.
- Dificultades principales.
- Movilidad reducida en miembro inferior izquierdo, que limita la posibilidad de desempeñar trabajos físicamente demandantes.
- Dificultad para mantener posturas prolongadas o realizar tareas que requieran fuerza y precisión fina con el miembro superior izquierdo.
- Impacto en la calidad de vida: Renuncia a su rol laboral, con una pérdida parcial de identidad profesional.

Rehabilitación: R.S inició su proceso de rehabilitación multidisciplinar en el HUMS tras presentar un ACV hemorrágico con hemiplejia izquierda. Recibió tratamiento en fisioterapia, terapia ocupacional, electroestimulación e hidroterapia. Durante los primeros días era totalmente dependiente y presentaba flacidez en el hemicuerpo afectado. A lo largo de cinco meses mostró una evolución significativa: recuperó movilidad distal en la mano, fuerza en el miembro inferior izquierdo y mejor control postural.
- Nivel de independencia
- Dependencia total al ingreso hospitalario
- Progresión hacia independencia parcial , tareas y ejercicios asistidos
- Dificultades principales.
- Vestido de la parte hemipléjica (calzado y medias en específico)
- Subida y bajada de escaleras
- Impacto en la calidad de vida.
- La evolución positiva en la rehabilitación mejoró la autoestima del paciente.

Actividades terapéuticas de prevención/progresión:
Las actividades terapéuticas realizadas con R.S estuvieron dirigidas tanto a la recuperación funcional como a la prevención de complicaciones secundarias propias de la hemiplejia. Se aplicaron ejercicios para estimular la movilidad proximal y distal del miembro superior afectado, fortalecimiento de la musculatura intrínseca de la mano, entrenamiento en actividades de vestido y trabajo del equilibrio en sedestación y bipedestación.
- Nivel de independencia
- Inicialmente dependiente total para la realización de actividades terapéuticas (ejercicios pasivos y asistencia completa).
- Progresión hacia independencia parcial, con ejecución activa-asistida de tareas.
- Dificultades principales.
- Limitación de la movilidad proximal del hombro y codo
- Fatiga durante actividades que impliquen movilidad
- Problemas de equilibrio
- Impacto en la calidad de vida.
- La terapia ha mejorado la movilidad funcional
- Refuerzo de la motivación al percibir avances concretos, aumentando su confianza en el proceso rehabilitador y mejorando su rol dentro del entorno familiar.

### 4. Barreras y facilitadores

Barreras:
- Físicas: Limitación en la movilidad de la cadera izquierda debido a la prótesis, que impide una flexión completa y dificultad para vestirse la parte inferior.
- Motora: Hemiplejia izquierda que afecta la movilidad tanto de la mano como de la pierna izquierda, impidiendo la realización de actividades básicas de la vida diaria (AVD) sin asistencia.
- Cognitiva: A pesar de que no presenta alteraciones cognitivas importantes, su dependencia en actividades de la vida diaria limita su autonomía.

Facilitadores:

- Rehabilitación multidisciplinaria: El acceso a servicios de fisioterapia, electroterapia y terapia ocupacional en un hospital especializado es un facilitador clave en su proceso de rehabilitación.
- Apoyo familiar: La presencia de su esposa e hijo, y el entorno con ascensor, facilitan su movilización y bienestar durante el proceso de recuperación.

### 5. Mapa de dolor (Pain Points)

Fatiga y frustración en la movilidad: El paciente presenta fatiga y dolor al caminar, especialmente cuando intenta usar su pierna afectada para dar un paso. A pesar de la rehabilitación, su movilidad limitada lo hace depender de otros para tareas cotidianas.
Dependencia en las actividades de la vida diaria: El paciente experimenta dificultad para vestirse la parte inferior debido a la limitación en la movilidad de la cadera y la hemiplejia. Aunque ha mejorado en su capacidad para realizar algunas actividades de la vida diaria (AVD), aún necesita ayuda externa.
Dolor y limitación en el movimiento de la mano y codo izquierdo: En las primeras fases de la rehabilitación, el paciente experimentó una flacidez severa en su brazo y mano izquierda. A pesar de que en el tiempo posterior se ha logrado cierto movimiento en el pulgar, aún necesita asistencia para realizar movimientos más complejos y continuar con su rehabilitación.

### 6. Expectativas del usuario

- R.S. busca recuperar la movilidad suficiente para poder caminar sin la ayuda del bastón, especialmente en trayectos cortos dentro de su hogar o en lugares accesibles.
- A pesar de los desafíos con la movilidad de su cadera y pierna izquierda, el paciente tiene el objetivo de recuperar la autonomía para vestirse sin depender de otras personas.
- Las expectativas del paciente se centran en recuperar la independencia funcional, especialmente en su movilidad y tareas domésticas, con el objetivo de mejorar su calidad de vida y participación en actividades cotidianas, a pesar de las limitaciones físicas ocasionadas por el ictus.

Bibliografía
[1] National Heart, Lung, and Blood Institute (NHLBI), “¿Qué es un accidente cerebrovascular?,” NHLBI, NIH, 14-Jul-2023. [Online]. Available: https://www.nhlbi.nih.gov/es/salud/accidente-cerebrovascular
[2] National Heart, Lung, and Blood Institute (NHLBI), “Accidente cerebrovascular: Causas y factores de
riesgo,” | NHLBI, | NIH, | última | actualización | 17-Jul-2023. | [Online]. | Available:
https://www.nhlbi.nih.gov/es/salud/accidente-cerebrovascular/causas
[3] Pigretti, S. G., Alet, M. J., Mamani, C. E., Alonzo, C., Aguilar, M., Álvarez, H. J., et al. (2019). Consenso sobre accidente cerebrovascular isquémico agudo. Medicina (Buenos Aires), 79(Supl. 2), 1–46.
[4]
Steiner T, Salman RA-S, Beer R, et al. European Stroke Organisation (ESO) Guidelines for the Management of Spontaneous Intracerebral Hemorrhage. International Journal of Stroke. 2014;9(7):840-855. doi:10.1111/ijs.12309 (https://doi.org/10.1111/ijs.12309)
[5] E Wurzinger, H., Abzhandadze, T., Rafsten, L., & Sunnerhagen, K. S. (2021). Dependency in Activities of Daily Living During the First Year After Stroke. Frontiers in neurology, 12, 736684. https://doi.org/10.3389/fneur.2021.736684
[6]Wade, D. T., & Hewer, R. L. (1987). Motor loss and swallowing difficulty after stroke: frequency,
recovery, | and | prognosis. | Acta | neurologica | Scandinavica, | 76(1), | 50–54.
https://doi.org/10.1111/j.1600-0404.1987.tb03543.x
[7] Mayo Clinic Staff, “Accidente cerebrovascular – Síntomas y causas,” Mayo Clinic (sitio en español), 13
de | diciembre | de | 2024. | [En | línea]. | Disponible:
https://www.mayoclinic.org/es/diseases-conditions/stroke/symptoms-causes/syc-20350113
[8] World Health Organization, “Stroke / cerebrovascular accident,” Eastern Mediterranean Regional Office (EMRO), disponible en: https://www.emro.who.int/health-topics/stroke-cerebrovascular-accident/index.html
[9] W. J. Powers et al., “2018 Guidelines for the Early Management of Patients With Acute Ischemic Stroke,” Stroke, vol. 49, no. 3, pp. e46-e110; American Heart Association/American Stroke Association, 2018. Disponible en: https://www.ahajournals.org/doi/10.1161/str.0000000000000158
[10] Centers for Disease Control and Prevention (CDC), “About Stroke,” disponible en: https://www.cdc.gov/stroke/about/index.html
[11] F. Shehjar, B. Maktabi, Z. A. Rahman, G. A. Bahader, A. W. James, A. Naqvi, R. Mahajan, and Z. A. Shah, "Stroke: Molecular mechanisms and therapies: Update on recent developments," Neurochem. Int., vol. 162, p. 105458, Jan. 2023, doi: 10.1016/j.neuint.2022.105458
[12] Markus, H. S., & Michel, P., "Treatment of posterior circulation stroke: Acute management and secondary prevention," Int. J. Stroke, vol. 17, no. 7, pp. 723-732, Aug. 2022, doi: 10.1177/17474930221107500
[13] Rahayu, U. B., Wibowo, S., Setyopranoto, I., & Romli, M. H. (2020). Effectiveness of physiotherapy interventions in brain plasticity, balance and functional ability in stroke survivors: A randomized controlled trial. NeuroRehabilitation, 47(4), 463-470. doi: 10.3233/NRE-203210 (https://doi.org/10.3233/NRE-203210)
[14] Lee, E. C., Ha, T. W., Lee, D. H., Hong, D. Y., Park, S. W., Lee, J. Y., Lee, M. R., & Oh, J. S., "Utility of Exosomes in Ischemic and Hemorrhagic Stroke Diagnosis and Treatment," Int. J. Mol. Sci., vol. 23, no. 15,

p. | 8367, | Jul. | 2022, | doi: | 10.3390/ijms23158367. | [Online]. | Available:
https://pubmed.ncbi.nlm.nih.gov/35955498/.
[15] Nukovic, J. J., Opancina, V., Ciceri, E., Muto, M., Zdravkovic, N., Altin, A., Altaysoy, P., Kastelic, R., Velazquez Mendivil, D. M., Nukovic, J. A., Markovic, N. V., Opancina, M., Prodanovic, T., Nukovic, M., Kostic, J., & Prodanovic, N., "Neuroimaging Modalities Used for Ischemic Stroke Diagnosis and Monitoring," Medicina (Kaunas), vol. 59, no. 11, p. 1908, Oct. 2023. doi: 10.3390/medicina59111908.
[16] S. Israely, G. Leisman, and E. Carmeli, “Improvement in arm and hand function after a stroke with
task-oriented | training,” | BMJ | Case | Rep., | 2017. | [Online]. | Available:
https://pmc.ncbi.nlm.nih.gov/articles/PMC5372193/.
[17] A. E. Rodríguez-Lázaro y F. Ortiz-Corredor, “Cambios en la recuperación de la función motora en pacientes con accidente cerebrovascular crónico,” Iatreia, vol. 29, no. 2, pp. 213–224, Apr.–Jun. 2016. [Online]. Available: http://www.scielo.org.co/scielo.php?pid=S0121-07932016000200002&script=sci_arttext
[18] J. Seetge, B. Cséke, Z. N. Karádi, E. Szalai, V. Gaál y L. Szapáry, “Subsequent Acute Ischemic Stroke in a Patient with Monocular Vision Loss Associated with Isolated Internal Carotid Artery Occlusion: A Case Report,” Neurol. Int., vol. 17, no. 1, art. 3, 26-dic. 2024, doi: 10.3390/neurolint17010003.
[19] Pérez Pérez, S. (2022). Intervención desde Terapia Ocupacional en un caso clínico de hemiplejia a consecuencia de un ictus hemorrágico

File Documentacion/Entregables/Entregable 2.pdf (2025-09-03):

# ENTREGABLE 2

Integrantes:
Carla Ulloa Florián
Nahir Valladares Santur
Luciana Vega Llanos
Carla Victoria Quispe
Stela Villagomez Altamirano Almendra Yataco Diaz

Profesor:
Juan Manuel Zuñiga

Curso:
Fundamentos de Biodiseño

2025

PARTE 1

### 1. Información Personal

a. Nombre y dirección del cliente, información de contacto: No especificado
b. Fecha de nacimiento, género: Mujer, 55 años
c. Médico (s) y especialistas: No especificado
d. Fuente de referencia y motivo de la referencia: Secuelas de ACV hemorrágico con hemiplejía espástica derecha
e. Regímenes de tratamiento médico o terapéutico existentes y sus objetivos:
i. Disminuir espasticidad en brazo y mano (estiramientos, férulas, toxina botulínica)
ii. | Favorecer funcionalidad de la mano izquierda como dominante
iii. | Reentrenamiento en AVD
iv. | Mejorar seguridad de la marcha y prevenir caídas

### 2. Financiamiento

a. Fuentes de financiamiento para la evaluación, el equipo, el seguimiento y la capacitación: No especificado
b. Política de la fuente de financiamiento, criterios de aprobación y flexibilidad: No especificado
c. Aseguradora, número de póliza, nombre y número de teléfono de contacto: No especificado
d. Prioridad de los elementos, si el financiamiento es limitado. Alternativas de financiamiento: No especificado

### 3. Diagnósticos e historial médico

a. Diagnóstico principal, diagnósticos secundarios, inicio, tratamiento, pronóstico:
i. Diagnóstico principal: Hemiplejía derecha espástica post ACV hemorrágico
ii. | Inicio: 6 meses atrás
iii. | Pronóstico neurológico: Déficit motor residual permanente
iv. | Pronóstico funcional: recuperación parcial, limitación persistente en
| mano derecha
b. Contraindicaciones o precauciones relacionadas con el uso de la tecnología: No especificado
c. Cirugías pasadas, planes quirúrgicos futuros: No especificado
d. Medicamentos, dosis, motivo: No especificado
e. Dolor, molestias, quejas o inquietudes: Mano derecha en flexión permanente con pobre apertura voluntaria, paso inseguro y despertares nocturnos
f. Función motora oral para el habla y la deglución: Cuenta con una leve disartria y se alimenta con su mano no dominante g. Estado cardíaco y respiratorio, resistencia: No especificado
h. Función intestinal y vesical: No especificado

### 4. Estado psicosocial:

a. Interacción social, comunicación, cognición.
- Su entorno se relaciona con esposo e hija, era costurera antes del evento
b. Conciencia de seguridad, juicio.
- Estado de conciencia: lúcida, leve
- disartria
c. Comportamientos, rasgos de personalidad.
- Era costurera por lo que se le considera una persona creativa
- Tolerante y de aprendizaje rápido
d. Motivación, aprendizaje, sistema de apoyo.
- Desea Disminuir espasticidad en brazo y mano (estiramientos, férulas, toxina botulínica).
- Favorecer funcionalidad de la mano izquierda como dominante.
- Reentrenamiento en AVD.
- Mejorar la seguridad de la marcha y prevenir caídas.
e. Actitud, tolerancia a la tecnología.
- Usa un baston con 4 apoyos por lo que interactúa de forma escasa con otros dispositivos tecnológicos
f. Situación de vida y entorno, influencias culturales, dinámica familiar.
- vive con su esposo e hija
g. Escuela, vocación, empleo, programa diurno, recreación, actividades de ocio.
- Era costurera y es madre de familia
h. Rutina diaria, actividades, equipo utilizado, posición preferida.
- Para caminar utiliza un bastón de cuatro apoyos. Es independiente para alimentarse usando la mano izquierda. Además posee despertares nocturnos

### 5. Estado neuromuscular y musculoesquelético

a. Estatura, peso.
- No especifica
b. Articulaciones: rango de movimiento (ROM), tolerancia a fuerzas/presión correctivas.

- menciona la condición general de la paciente, como la hemiplejía espástica y la flexión permanente de la mano derecha, pero no incluye datos específicos sobre el rango de movimiento de las articulaciones o su tolerancia a la corrección física.
c. Músculos: tono, espasticidad, flexibilidad, rigidez, temblor, fuerza, fatiga muscular.
- Presenta espasticidad moderada en el hemicuerpo derecho (Ashworth 2-3).
d. Influencias neurológicas: reflejos primitivos, reacciones, influencias anormales.
- déficit motor residual permanente, no especifica
e. Postural: control postural, equilibrio al sentarse y al estar de pie, estabilidad, recuperación.
- La marcha es con un bastón de cuatro apoyos y se describe como insegura.
f. Control motor: calidad del movimiento, coordinación, resolución, tiempo de reacción.
- Movilidad de apertura de la mano derecha reducida y marcha despacio con dificultades.
g. Patrones y estrategias de movimiento: voluntarios, espontáneos.
- La mano derecha está en flexión permanente, con una pobre apertura voluntaria

### 6. Estado neuromuscular y musculoesquelético

a. Postura y posicionamiento óptimos para acceder a las tecnologías.
- Técnicas basadas en asimetría corporal y equilibrio corporal es probable que el paciente debido a su condición desarrolle asimetría postural.
- Un mejor acceso en la mano izquierda, donde no se necesitan movimientos de alcance excesivos o posturas forzadas.
b. Información adicional para la evaluación de la sedestación:
i. La hemiplejía puede causar asimetrías posturales debido a la debilidad muscular en un lado del cuerpo.

ii. - Es posible que al tomar asiento, adopte una postura con el tronco inclinado hacia el lado sano.

- Requiere de un bastón de 4 apoyos

- Probablemente necesite adaptaciones para mantener una postura estable al sentarse y al realizar actividades.

iii. - La hemiplejía derecha ocasiona una alteración durante la marcha. El cuerpo afectado presenta espasticidad moderada, lo que restringe el movimiento y la flexibilidad. ocasionando una menor propulsión, equilibrio reducido y mayor gasto energético.

- La mano derecha se encuentra en poca movilidad, lo que limita
| su funcionalidad y el rango de movimiento. Esta postura anómala es una influencia biomecánica directa de la espasticidad, afectando las articulaciones del codo, la muñeca y la mano.
- La paciente probablemente depende más del lado izquierdo
| debido a su falta de equilibrio. Esta asimetría puede causar desequilibrios musculares y posturales, afectando la alineación del tronco y la pelvis, y aumentando el riesgo de caídas es por ello el uso del bastón.
iv. | El pronóstico funcional indica una "recuperación parcial" y una "limitación persistente en la mano derecha", lo que sugiere un potencial de corrección limitado, pero con posibilidad de mejoras funcionales a través de la rehabilitación. Las metas de rehabilitación incluyen disminuir la espasticidad con estiramientos, férulas y toxina botulínica, lo cual indica que hay tolerancia a fuerzas correctivas, pero que estas son necesarias

### 7. Afección de la piel

a. Afección de la piel, cicatrices, textura de los tejidos blandos, edema, color, palidez.
➔ Cicatrices: No se reportan cicatrices asociadas a intervenciones quirúrgicas o lesiones cutáneas.
➔ Textura de los tejidos blandos: Posible rigidez muscular y cambios por espasticidad en hemicuerpo derecho.
➔ Edema: No descrito en la historia, pero puede haber riesgo de edema en extremidad superior derecha por inmovilidad.
➔ Color / Palidez: No hay alteraciones descritas, piel normocoloreada.

b. Antecedentes o presencia de úlceras por presión, ubicación, causas desencadenantes, circunstancias circundantes, tratamiento, riesgos.
➔ Presencia: No se mencionan úlceras por presión en el caso.
➔ Ubicación: No aplica.
➔ Causas desencadenantes: En pacientes con hemiplejía, el riesgo es la inmovilidad prolongada y presión en zonas óseas.
➔ Circunstancias circundantes: Movilidad reducida, riesgo aumentado en talones, sacro y codo derecho.
➔ Tratamiento: Prevención mediante cambios posturales y cuidados de la piel.
➔ Riesgos: Riesgo moderado-alto de desarrollar úlceras por presión debido a hemiplejía derecha y movilidad reducida.

### 8. Función sensorial

a. Visión: visión funcional, agudeza, percepción visual.

No se reportan alteraciones en el caso clínico, visión conservada.

b. Audición.

No se describen problemas auditivos, audición conservada.

c. Percepción sensorial: tacto, propiocepción, sentido kinestésico.

El caso no menciona hallazgos específicos, no evaluado o no descrito.

### 9. Habla, lenguaje y comunicación

a. Capacidad de lenguaje expresivo y receptivo.

Paciente con leve disartria.

b. Habla, articulación.

Habla y articulación afectadas por la disartria.

c. Nivel cognitivo, capacidad de aprendizaje, capacidad de atención, estado académico/educativo.

La paciente se encuentra lúcida.

d. Uso y experiencia con dispositivos generadores de habla.

Ninguno que se reporte.

### 10. Desempeño funcional, de habilidades y de tareas

a. Necesita de asistencia parcial para algunas actividades diarias, utiliza un bastón con 4 apoyos para caminar, pero puede comer independientemente con la mano izquierda.
b. Para su cuidado personal no puede bañarse y vestirse sin ayuda. Además, puede realizar tareas sencillas para hacerse de comer, con una sola mano (solo la mano izquierda).
c. Puede hacerse de comer con su mano izquierda, puede que sea limitado. Cabe recalcar que su mano derecha no es funcional y necesita de apoyo para mantener su postura.
d. Era costurera, pero actualmente no puede volver a su trabajo. Puede ayudar en tareas del hogar pero con ciertas limitaciones.
e. Puede realizar actividades básicas como escribir o sostener utensilios con la mano izquierda y requiere de adaptaciones para superficies de trabajo.
f. Puede usar estas con la mano izquierda, pero puede que con un poco de lentitud, algunas estrategias que la puede ayudar es un teclado adaptado, por ejemplo.

### 11. Movilidad personal

a. Camina con un bastón de 4 apoyos, puede que sea inseguro, además de tener una velocidad muy limitada y un mayor riesgo de caídas y accidentes. Tiene una desviación en su caminar por fragilidad del hemicuerpo derecho.
b. Traslados (cama, inodoro, bañera, vehículo), para actividades como estas es parcialmente independiente, pero puede que le demoren más de lo normal, excepto para el vehículo que si necesitara de ayuda. Puede necesitar de agarres de seguridad en la ducha y baño.
c. No se especifica como lo habitual, pero puede que sea una mejor opción para moverse hacia tramos extensos.

### 12. Transporte comunitario

a. Vehículos: No especifica, pero se puede asumir debido a su marcha insegura que depende de un vehículo familiar o de algún servicio de taxi.
b. Entrada y salida: No especifica
c. Viaje en silla de ruedas en un vehículo en movimiento: No especifica
d. Almacenamiento de la silla de ruedas: No aplica, usa bastón.

### 13. Entornos

a. Todos los sitios: Vive en su hogar junto a su esposo y su hija; antes trabajaba como costurera.

b. Accesibilidad: Ella presenta marcha insegura con bastón, lo que genera un riesgo alto en la vía pública.
c. Entorno físico: No especifica
d. Entorno psicosocial: Vive con su familia; sin embargo, puede enfrentar poca accesibilidad laboral por ser una persona discapacitada.
e. Compatibilidad con la tecnología: Hay integración parcial de tecnología de asistencia como bastón de 4 apoyos.

### 14. Historial de equipos anteriores

a. Qué funcionó, qué no, por qué.

La paciente usaba un bastón de 4 apoyos para la marcha. Este equipo le permitió mejorar su estabilidad al caminar, lo cual es clave para su movilidad y seguridad. Sin embargo, su marcha sigue siendo insegura, lo que indica que el bastón no ha sido completamente efectivo para solucionar el problema de la inseguridad en el paso.

Aunque el bastón ayuda en la marcha, la paciente sigue experimentando dificultades en su movilidad debido a la espasticidad en el hemicuerpo derecho. La espasticidad moderada (Ashworth 2-3) en el brazo y la mano derecha, junto con la flexión permanente de la mano derecha, continúan limitando la funcionalidad total del miembro afectado. Este tipo de espasticidad y la rigidez en la mano son problemas difíciles de manejar con equipos convencionales como bastones, y podrían requerir una combinación de intervenciones adicionales como férulas y técnicas de estiramientos.

b. Gustos, disgustos y preocupaciones del equipo.

Gustos: No se especifica.

Disgustos y preocupaciones: La paciente muestra problemas con la movilidad (camina con bastón de 4 apoyos y tiene un paso inseguro) y con la funcionalidad de la mano derecha (flexión permanente y pobre apertura voluntaria).

c. Tolerancia del cliente a la tecnología o al cambio.

Dado que la paciente tiene una espasticidad moderada y presenta dificultades para realizar movimientos con su mano derecha, parece estar adaptándose a las ayudas técnicas como bastones. Esto nos da un indicio de ser tolerante al cambio y la tecnología.

### 15. Equipo actual

a. Modelo, estilo, marca, número de serie: No se especifican detalles de marca o número de serie.
b. Características, componentes, peso, dimensiones: El equipo actual parece incluir un bastón de 4 apoyos.
c. Objetivos y justificación para elegir esta tecnología: El bastón de 4 apoyos está diseñado para ofrecer mayor estabilidad y equilibrio que los bastones tradicionales. Esto es fundamental para la paciente, que presenta un paso inseguro y un riesgo de caídas debido a la espasticidad y la debilidad muscular en su hemicuerpo derecho. El tratamiento está diseñado para mejorar la movilidad de la paciente y su independencia en las actividades de la vida diaria (AVD), así como para reducir los riesgos de caídas.
d. Vida útil restante prevista de la tecnología: antigüedad, estado, historial de reparaciones: No se proporciona información sobre la antigüedad de los equipos ni el historial de reparaciones.
e. Gustos, disgustos e inquietudes del cliente y del cuidador: No se especifica, pero se puede asumir que la paciente preferiría una mayor independencia en las actividades cotidianas y en la movilidad.
f. Eficacia funcional del equipo actual, equipo utilizado correctamente: La paciente parece estar usando correctamente el equipo, como el bastón para caminar, aunque sigue teniendo dificultades en la funcionalidad de la mano derecha.

PARTE 2 (Información ordenada)

A. Usuario/Paciente:
- Edad: 55 años
- Género: Femenino
- Contexto: vive con esposo e hija
- Situación y Habilidades:
- Antes de la enfermedad era costurera
- Posee una marcha insegura con ayuda técnica y un bastón de 4 apoyos
- Escasa funcionalidad de la mano derecha.
- posee una pobre apertura voluntaria.
B. Actividad:
Describe el conjunto de tareas a realizar por la persona con discapacidad (caso asignado).
- En sus actividades cotidianas realiza la alimentación con su mano izquierda, necesitando ayuda en la higiene, vestimenta, traslados y algunas tareas del hogar, especialmente en actividades que necesitan el uso de ambas manos. Además de necesitar de barandas de apoyo para movilizarse en su casa, sobre todo en la ducha y baño. Para la movilidad usa un bastón de cuatro apoyos, aún así presentando una marcha inestable. Debido a que ya no puede ser costurera, se ve en la obligación de realizar diferentes actividades en el hogar, al cual se le recomendaría contar con diversos apoyos acondicionados debido a su condición, manteniendo así su rol como esposa o madre. Finalmente, es fundamental que mantenga una buena asistencia a controles médicos o terapias.
C. Contexto:
Describe el entorno o contexto social, cultural y físico que rodea el entorno en el que debe realizarse la actividad. El entorno en el cual se realizará la actividad juega un papel crucial para su rehabilitación.
- Contexto social:
- Familia: La paciente vive con su esposo y hija, lo que proporciona una base sólida de apoyo emocional y físico. El involucramiento de la familia es fundamental, ya que pueden asistir, recordarle la importancia de la rehabilitación, y motivar a continuar el tratamiento. Además, pueden estar presentes para ayudarle en actividades de la vida diaria (AVD) que requieran asistencia debido a la limitación de su mano derecha.
- Servicios sociales y de salud: La disponibilidad de servicios de salud y rehabilitación (como fisioterapeutas, terapeutas ocupacionales y psicólogos) es esencial. La accesibilidad a estos servicios influirá en la continuidad y calidad de su tratamiento.
- Contexto cultural:
- Percepción de la discapacidad: Las personas con discapacidades pueden enfrentar prejuicios o estigmatización, lo que puede afectar la disposición de la paciente a aceptar su condición y utilizar ayudas técnicas.
- La educación cultural sobre la importancia de las terapias físicas y el uso de dispositivos puede ser clave para garantizar el éxito del tratamiento.
- Apoyo comunitario: Si la comunidad tiene grupos de apoyo para personas con discapacidad o programas de integración social, la paciente podría beneficiarse de ellos. Estos espacios pueden proporcionar apoyo emocional y la oportunidad de compartir experiencias con otros que atraviesan situaciones similares.
- Contexto físico:
- Adaptación del entorno doméstico: Modificaciones en el hogar son esenciales para permitir que la paciente se mueva con seguridad y facilidad.
- Accesibilidad en la comunidad: La capacidad de la paciente para interactuar con el mundo fuera de su hogar dependerá de la accesibilidad de la infraestructura urbana ya sea rampas, espacios cómodos para su traslado y aceras sin obstáculos.
D. Tecnología:
Dispositivos o estrategias utilizadas para cerrar la brecha entre las capacidades de la persona y las demandas del entorno.
1.- Exoesqueletos para ayudar la movilidad de la paciente
Ejemplo: exoesqueleto HANK

El exoesqueleto HANK :

[1]

2.-Estimulación eléctrica funcional
La estimulación eléctrica funcional (FES) es una buena opción para personas con hemiplejía después de un ACV porque ayuda a que los músculos se activen y vuelvan a moverse, incluso cuando al inicio casi no hay movilidad. El estudio de Marquez-Chin y colegas (2017) mostró que quienes recibieron este tratamiento lograron mejorar la fuerza y el uso del brazo afectado, además de ganar más independencia para hacer cosas básicas del día a día. [2]

3.-Comunicación asistida para ayudar su disartria.[3]

El uso de un teléfono celular en la terapia ha demostrado mejorar la claridad y la articulación del habla.

En este tipo de terapia, el celular se convierte en una herramienta diaria para el paciente. A través de una aplicación especial, se le proponen ejercicios de pronunciación, repetición de sílabas, palabras y frases, con retroalimentación inmediata que le permite darse cuenta de sus avances.

Bibliografía.

[1] Gil-Agudo Á, Megía-García Á, Pons JL, Sinovas-Alonso I, Comino-Suárez N, Lozano-Berrio V, Del-Ama AJ. Exoskeleton-based training improves walking independence in incomplete spinal cord injury patients: results from a randomized controlled trial. J Neuroeng Rehabil. 2023 Mar 24;20(1):36. doi: 10.1186/s12984-023-01158-z. Erratum in: J Neuroeng Rehabil. 2023 Nov 18;20(1):160. doi: 10.1186/s12984-023-01281-x. PMID: 36964574; PMCID: PMC10039497.
[2] Marquez-Chin C, Bagher S, Zivanovic V, Popovic MR. Functional electrical stimulation therapy for severe hemiplegia: Randomized control trial revisited. Can J Occup Ther. 2017 Apr;84(2):87-97. doi: 10.1177/0008417416668370. Epub 2017 Jan 17. PMID: 28093928.
[3] Kim Y, Kim M, Kim J, Song TJ. Smartphone-Based Speech Therapy for Poststroke Dysarthria: Pilot Randomized Controlled Trial Evaluating Efficacy and Feasibility. J Med Internet Res. 2024 Apr 25;26:e56417. doi: 10.2196/56417. PMID: 38509662; PMCID: PMC11082729.

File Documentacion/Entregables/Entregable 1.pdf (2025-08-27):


# ENTREGABLE 1

Integrantes:
Carla Ulloa Florián
Nahir Valladares Santur
Luciana Vega Llanos
Carla Victoria Quispe
Stela Villagomez Altamirano Almendra Yataco Diaz

Profesor:
Juan Manuel Zuñiga

Curso:
Fundamentos de Biodiseño

2025


ESCLEROSIS LATERAL AMIOTRÓFICA (ELA)

### 1. FICHA DE LA ENFERMEDAD

Sistema afectado: También conocida como enfermedad de Lou Gehrig, la Esclerosis Lateral Amiotrófica es una enfermedad neurodegenerativa progresiva que afecta al sistema nervioso.
Descripción anatómica/fisiológica: Trastorno neurodegenerativo progresivo que causa la degeneración y muerte de las motoneuronas, lo que resulta en debilidad muscular e insuficiencia respiratoria conforme la enfermedad progresa.
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

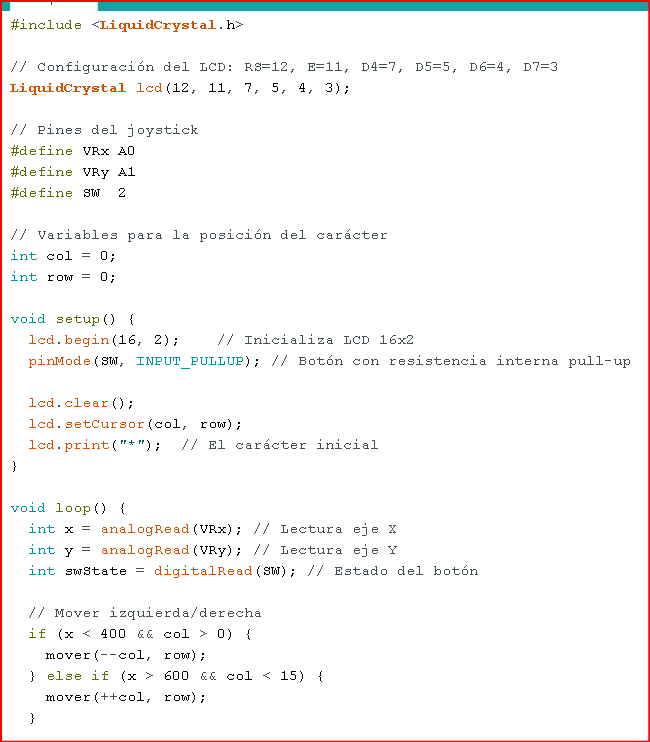
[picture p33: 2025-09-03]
Documentacion/Talleres en clase/Taller electronica II/3 Codigo de sistema de navegación I.png

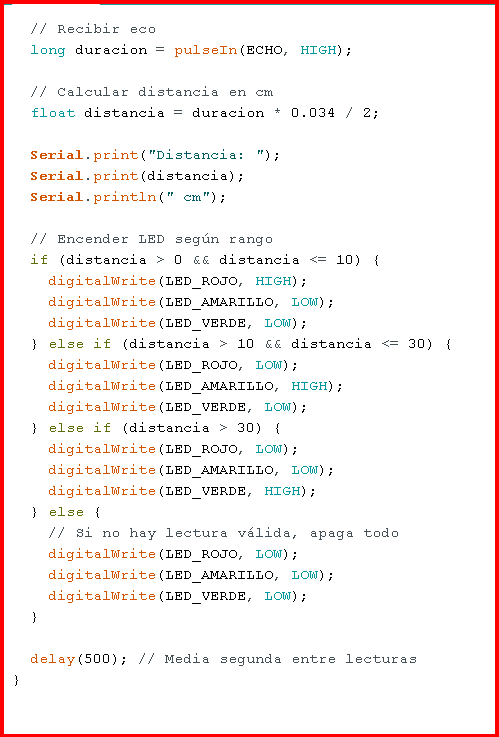
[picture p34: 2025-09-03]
Documentacion/Talleres en clase/Taller electronica II/2 Código para el sistema de detección de proximidad con leds II.png

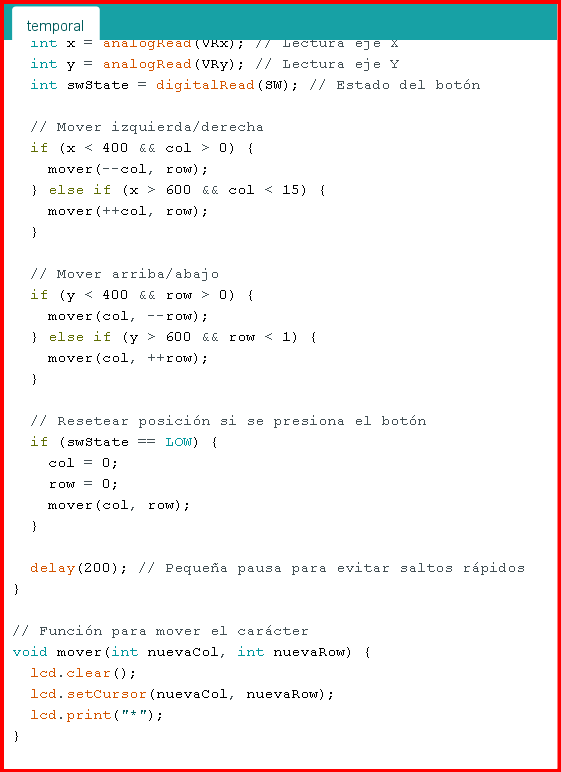
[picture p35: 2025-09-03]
Documentacion/Talleres en clase/Taller electronica II/3 Codigo de sistema de navegación II.png

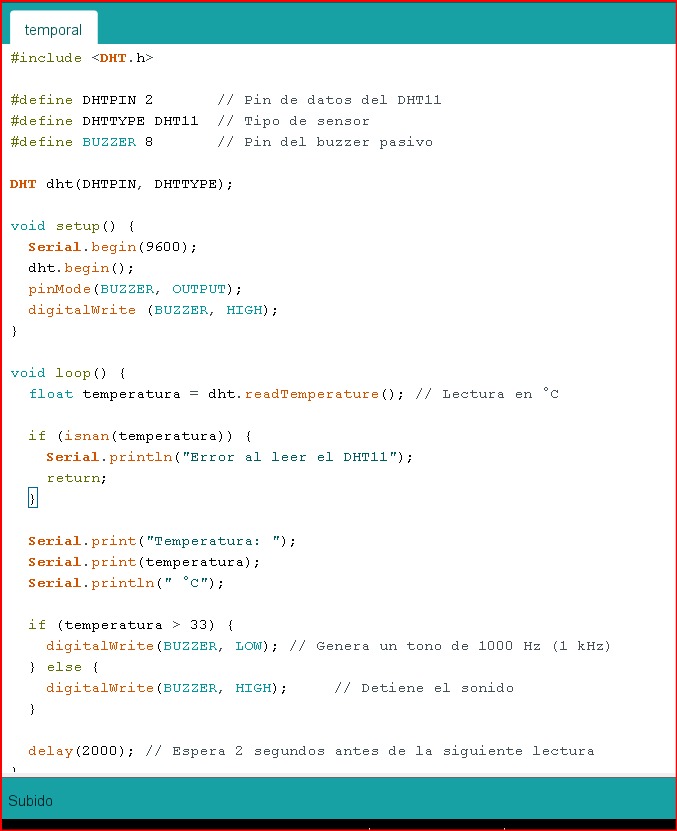
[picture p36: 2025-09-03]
Documentacion/Talleres en clase/Taller electronica II/1 Código para el sistema de alarma por temperatura.jpeg

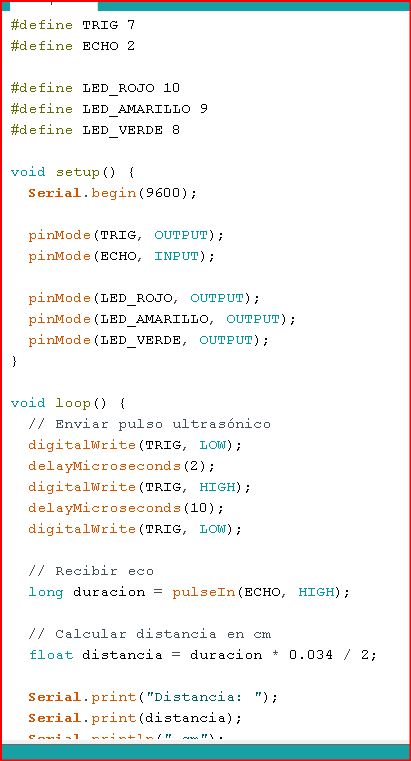
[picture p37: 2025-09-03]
Documentacion/Talleres en clase/Taller electronica II/2 Código para el sistema de detección de proximidad con leds I.png

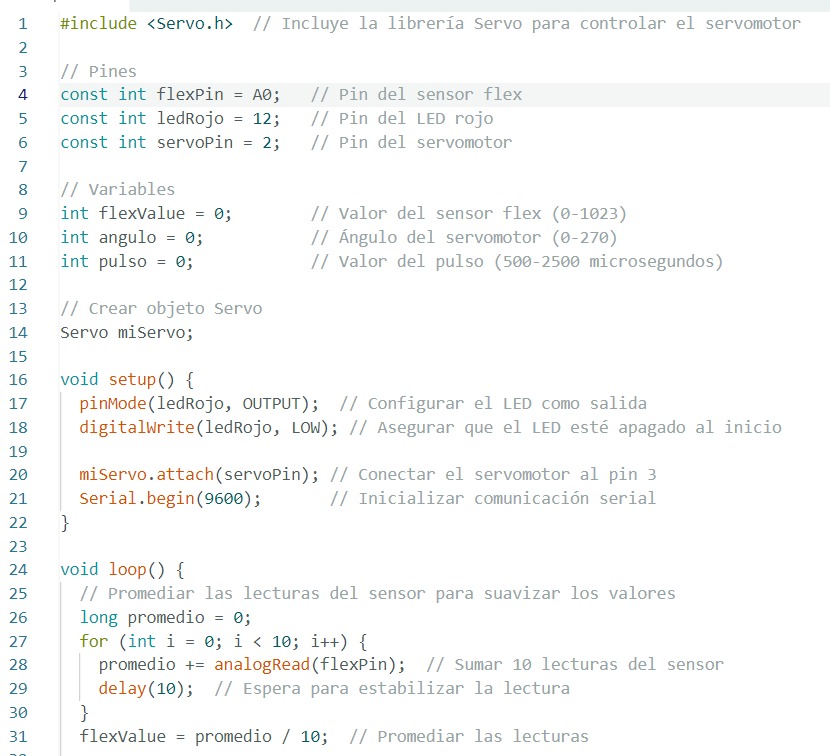
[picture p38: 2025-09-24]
Documentacion/Talleres en clase/Taller 6 - Actuadores/Actividad 2/Código 1.jpeg

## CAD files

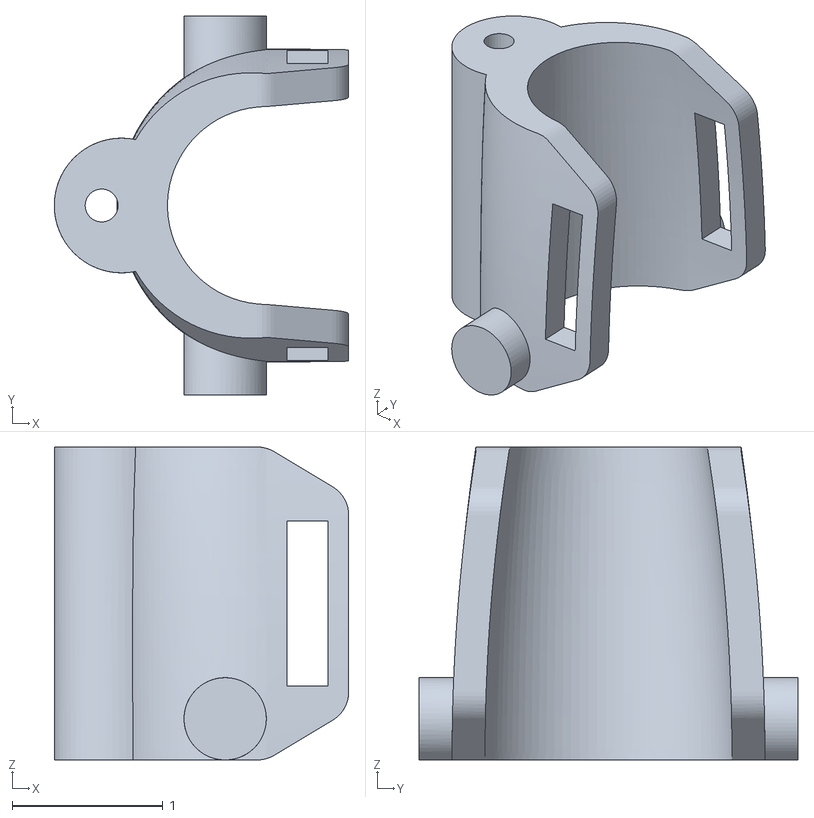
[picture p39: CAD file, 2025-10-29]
Documentacion/Entregables/Entregable 9/Exoesqueleto +férula stl/Dedo anular/Anular 3.stl
1.95 x 2.51 x 2.08

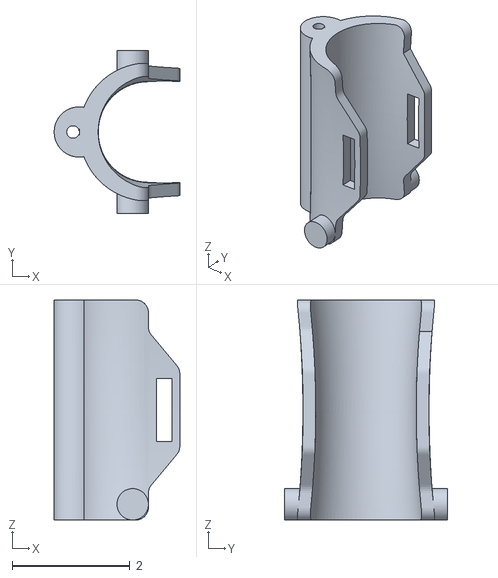
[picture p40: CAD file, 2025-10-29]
Documentacion/Entregables/Entregable 9/Exoesqueleto +férula stl/Dedo medio/Medio 1.stl
2.13 x 2.77 x 3.73

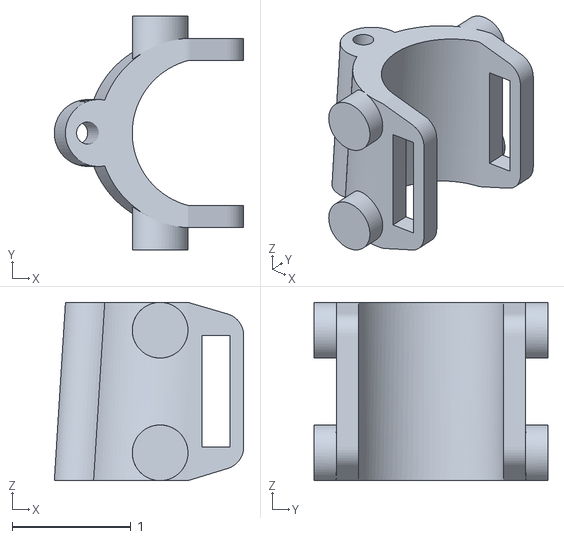
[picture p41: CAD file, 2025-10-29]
Documentacion/Entregables/Entregable 9/Exoesqueleto +férula stl/Dedo meñique/Meñique 2.stl
1.60 x 1.97 x 1.50

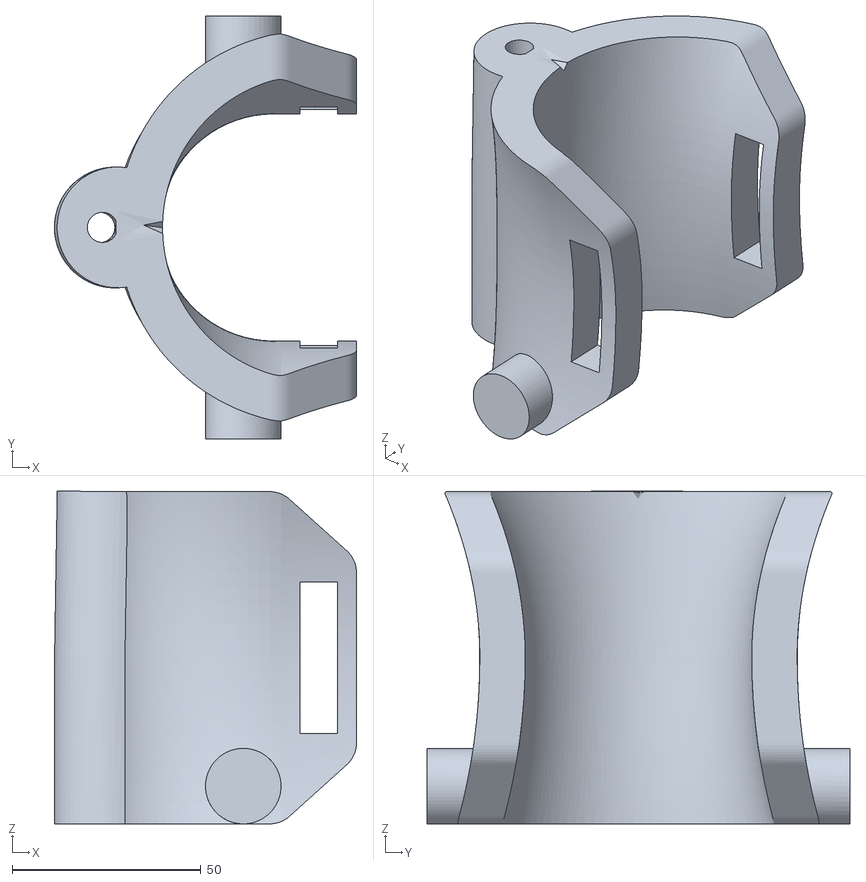
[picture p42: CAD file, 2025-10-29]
Documentacion/Entregables/Entregable 9/Exoesqueleto +férula stl/Dedo pulgar/Pulgar 1.stl
80.0 x 112.0 x 88.1

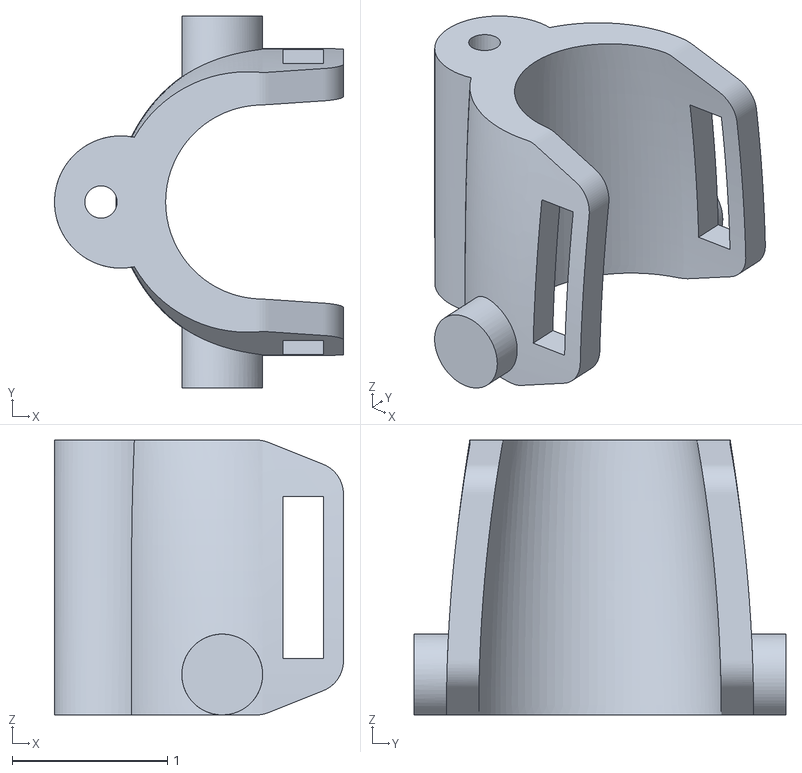
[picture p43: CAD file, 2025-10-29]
Documentacion/Entregables/Entregable 9/Exoesqueleto +férula stl/Dedo índice/Índice 3.stl
1.86 x 2.40 x 1.77

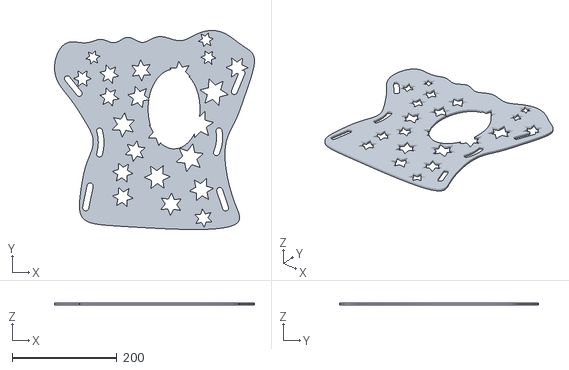
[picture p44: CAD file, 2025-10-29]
Documentacion/Entregables/Entregable 9/Exoesqueleto +férula stl/Férula.stl
382.5 x 380.8 x 4.70

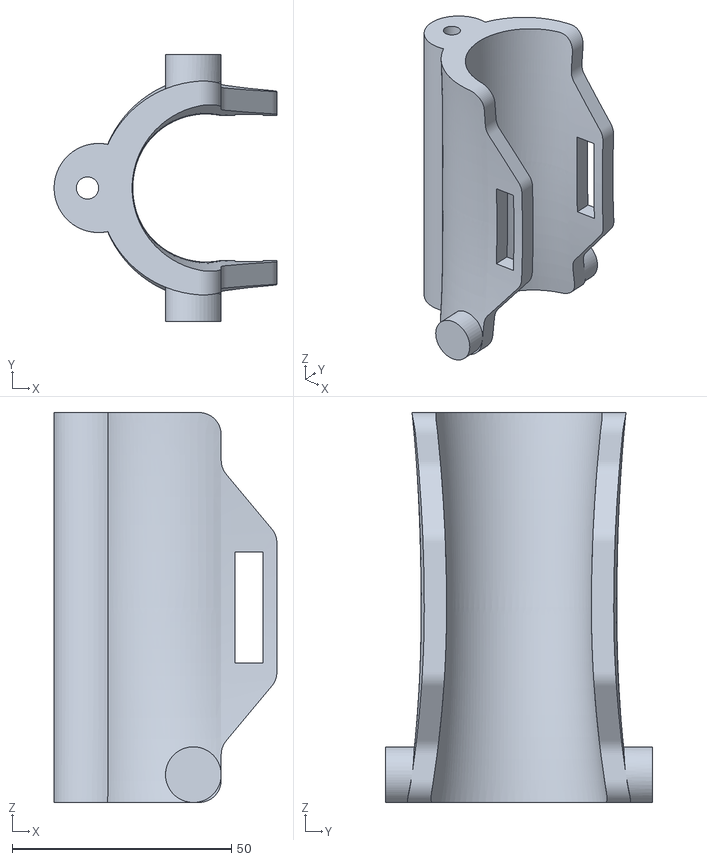
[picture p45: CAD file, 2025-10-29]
Documentacion/Entregables/Entregable 9/Exoesqueleto +férula stl/Dedo anular/Anular 1 (corregido).stl
50.8 x 61.0 x 88.9

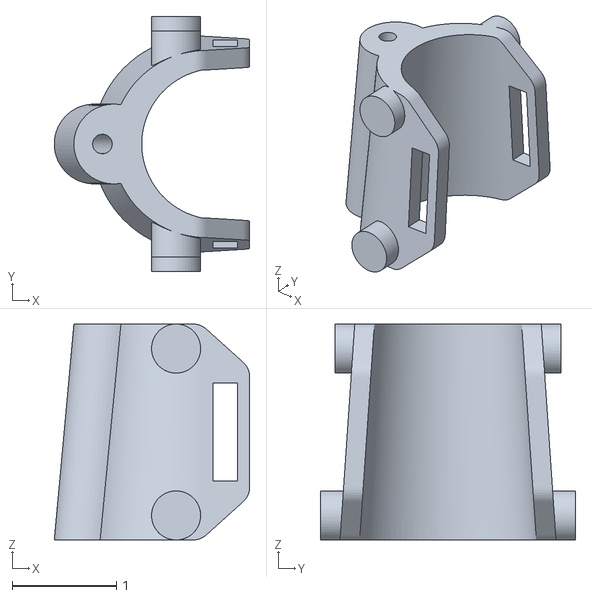
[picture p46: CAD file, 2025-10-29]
Documentacion/Entregables/Entregable 9/Exoesqueleto +férula stl/Dedo medio/Medio 2.stl
1.87 x 2.44 x 2.07

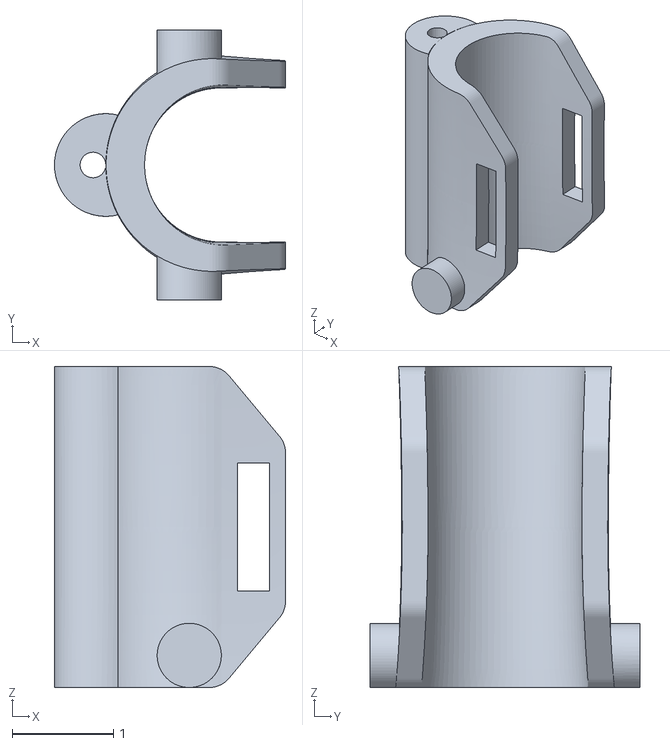
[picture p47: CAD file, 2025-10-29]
Documentacion/Entregables/Entregable 9/Exoesqueleto +férula stl/Dedo meñique/Meñique 1.stl
2.29 x 2.67 x 3.18

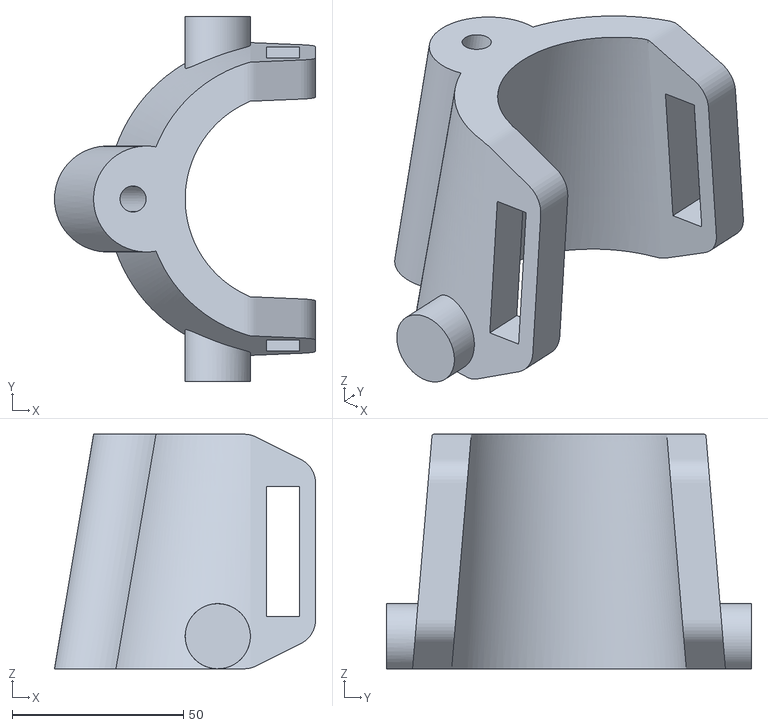
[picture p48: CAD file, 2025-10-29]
Documentacion/Entregables/Entregable 9/Exoesqueleto +férula stl/Dedo pulgar/Pulgar 2.stl
76.3 x 106.7 x 68.6

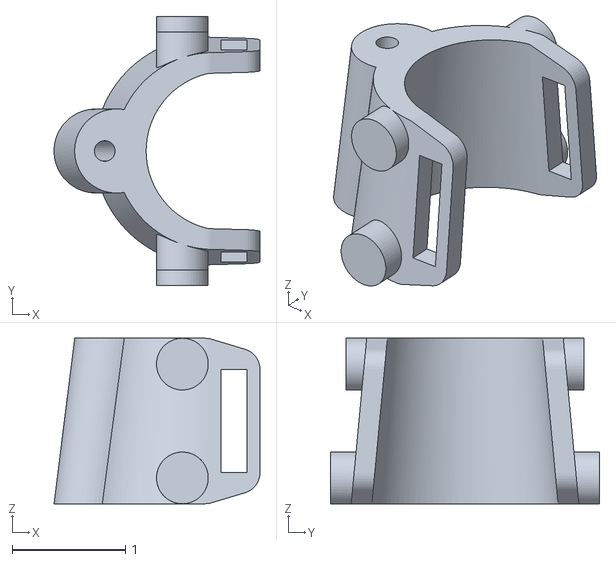
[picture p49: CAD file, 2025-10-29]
Documentacion/Entregables/Entregable 9/Exoesqueleto +férula stl/Dedo índice/Índice 2.stl
1.82 x 2.38 x 1.46

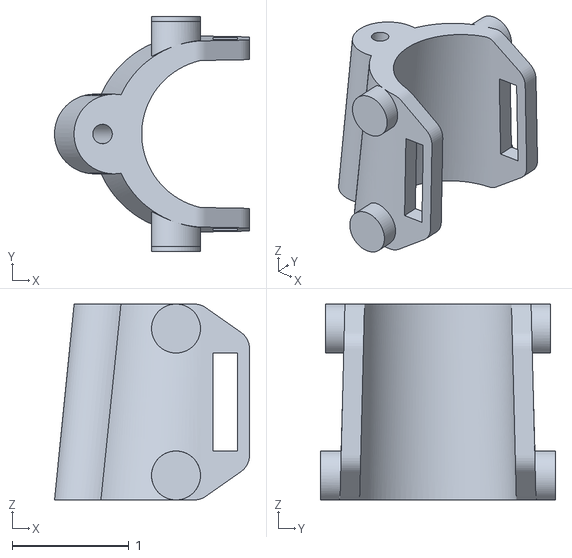
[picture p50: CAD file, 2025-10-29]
Documentacion/Entregables/Entregable 9/Exoesqueleto +férula stl/Dedo anular/Anular 2.stl
1.67 x 2.01 x 1.68

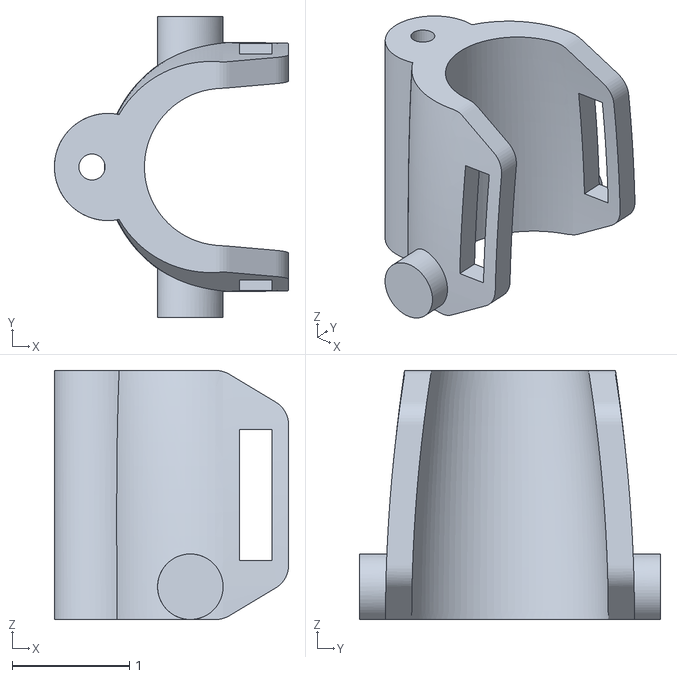
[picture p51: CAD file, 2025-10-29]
Documentacion/Entregables/Entregable 9/Exoesqueleto +férula stl/Dedo medio/Medio 3.stl
2.00 x 2.57 x 2.12

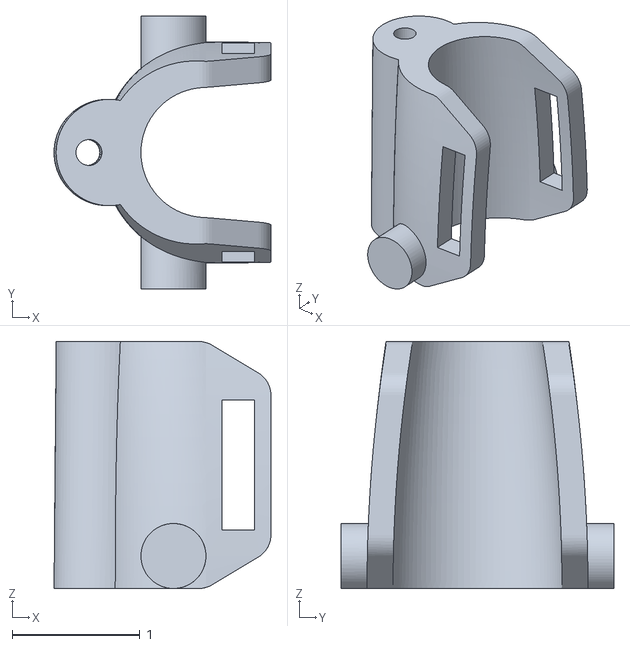
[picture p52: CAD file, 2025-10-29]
Documentacion/Entregables/Entregable 9/Exoesqueleto +férula stl/Dedo meñique/Meñique 3.stl
1.70 x 2.13 x 1.93

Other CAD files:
Documentacion/Entregables/Entregable 9/Exoesqueleto +férula stl/Dedo índice/Índice 1.stl

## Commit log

2025-08-20 Subida inicial de todas las carpetas con archivos
2025-08-20 Agregar imagen de WhatsApp
2025-08-20 Actualizar nombres de carpetas y estructura del proyecto
2025-08-27 Create Talleres de clase
2025-09-03 prueba para saber si se pueden subir videos
2025-09-17 Eliminar la carpeta Taller electronica II
2025-10-01 Se añadio la actividad 2
